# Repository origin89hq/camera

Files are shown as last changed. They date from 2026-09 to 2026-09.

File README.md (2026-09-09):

<picture>
  <source media="(prefers-color-scheme: dark)" srcset="https://raw.githubusercontent.com/origin89hq/brand/main/logos/origin89-horizontal-white.svg">
  Origin89
</picture>

# Origin89 camera

 Circuit specified, first copper drawn, nothing fabricated.

A trail camera that sends its pictures to the cabin over a Wi-Fi HaLow mesh,
so a site four hours from a road can be looked at without driving out. One
board, populated three ways: the camera, a relay that extends the mesh, and
the base at the cabin that talks to the controller. The processor is the
ESP32-P4 with a MIPI camera, chosen for night pictures; the radio is a HaLow
module.

| File | What it is |
| --- | --- |
| [CAMERA-MESH.md](CAMERA-MESH.md) | The product: what it does, the mesh, the power budget, what has to be measured before anything is built |
| [board/CAMERA-NODE.md](board/CAMERA-NODE.md) | The circuit specification the schematic is drawn from: blocks, rails, pin budget, the decisions left to draw time |
| [board/CAMERA-LAYOUT.md](board/CAMERA-LAYOUT.md) | The placement and routing rules, numbered `C-nn`, with their reasons |
| [board/layout/](board/layout/) | The placement and routing scripts that produced the first copper, in the order they run |
| [drawings/](drawings/) | The build and schedule drawings |

Every part is a candidate until it has been picked with its datasheet open.
The next step is the night-picture test on the P4 evaluation board; the
schematic is drawn against the result, not before it.

## Design source and exports

Design source: [`board/easyeda/origin89-camera.eprj2`](board/easyeda/), the
EasyEDA Pro project of this board alone, split out of the controller's.
Export of 2026-09-09: [`board/build/2026-09-09/`](board/build/2026-09-09/),
Gerbers, [bill of materials](board/build/2026-09-09/bom.csv),
[pick-and-place](board/build/2026-09-09/pick-and-place.csv), schematic PDF,
STEP and one DXF of every layer. The STEP is in Git LFS, so install
`git-lfs` before cloning or it comes down as a pointer file; it carries every
part but C59, which has no model. Nothing has been fabricated from it.

The Gerbers are checked by `tools/validate_gerbers.py`, the same script the
hardware repository runs on the controller, against
[`board/gerber-rules.json`](board/gerber-rules.json): the C-02 keep-outs at
the four mounting holes and the C-11 antenna void, layer by layer. It runs
in CI on every push and it is red on the 2026-09-09 export: the ground pour
reaches every mounting hole on all four layers, 29 mm² of copper inside the
3.5 mm keep-out at each, where C-02 wants none and C-03 wants the hole on
no net. The fix is the controller's: a prohibited region at each hole on
every copper layer, then the pours rebuilt. It is tracked as
[issue #1](https://github.com/origin89hq/camera/issues/1), and the check
goes green when the next export passes. Nothing has been fabricated from
this export, so no board carries the fault.

```sh
pip install gerbonara shapely
python tools/validate_gerbers.py board/gerber-rules.json board/build/2026-09-09/gerber.zip
```

Exports are filed with `tools/import_easyeda_export.py board <export folder>`,
the same way the [hardware repository](https://github.com/origin89hq/hardware)
files the controller's: the date becomes the directory and each file gets
the name its kind always gets.

## Licence

Design files and drawings under the CERN Open Hardware Licence version 2,
weakly reciprocal ([LICENSE](LICENSE)); the scripts under MIT OR Apache-2.0
([LICENSE-MIT](LICENSE-MIT), [LICENSE-APACHE](LICENSE-APACHE)).

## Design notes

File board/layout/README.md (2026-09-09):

# Camera node layout files

The DSL and placement files the camera board (`Camera_HaLow`, PCB3 in the
EasyEDA project) is laid out from, in the order they are used. The rules
they implement, and why, are in [CAMERA-LAYOUT.md](../CAMERA-LAYOUT.md).

| File | Tool | What it does |
|---|---|---|
| `camera-place.js` | `make_pcb_layout` | The whole-board placement: blocks, edge bands, satellites. Stochastic; six runs were needed and later ones regressed. Assemble the best, then repair by hand below |
| `padgeom.py` | library | Every pad's absolute position and shape, every part's centre and rotation, read from the newest router run under `$TMPDIR/easyeda-copilot-mcp/copilot-router/` (the PCB export has no pads). Any `run_pcb_router_dsl` call writes one, `camera-drc.js` being the cheapest |
| `p4_cluster.py` → `p4_cluster.json`, `p4-local.js` | `make_pcb_layout` on `p4-local.js` through the shim's `@local-placement` route, then `assemble_pcb_layout_on_current_pcbdoc` | The 48 parts pinned to the P4 (decoupling rings on all four sides, both crystals and their loads, the CSI series resistors, the flash, the core buck) at exact coordinates. Turns each two-pad part so its signal pad faces the chip, refuses to write while anything overlaps, prints each capacitor's pad-to-pin distance. Regenerating from the assembled board gives the identical file |
| `periphery.py` → `periphery.json`, `periphery-local.js` | same route as above | The repairs the checker found in the solver's placement outside the P4 cluster: the buttons off the U.FL, the LED boost inductor off its driver, the HaLow series resistors in the column at the module's pads with two straps moved out. Both generators share `Placement` in `padgeom.py` |
| `validate_camera_placement.py` | after every assembly | Measures every C-nn rule a placement can break, from the real pads, and refuses two parts that overlap. Run it on a fresh artifact (`camera-drc.js` first). Watched go red on the solver's placement before it was trusted |
| `csi_tracks.py` → `csi_tracks.json`, `csi-tracks-local.js` | same route as above, after the parts are placed | The seventeen nets the router could not do, drawn from the real pads: the MIPI lanes on both sides of their resistors (two crossings the connector's pin order forces, six vias), the D-PHY reference, both crystals with their loads. Refuses if any pad it relies on has moved, and if any pair's skew over the whole path passes C-20's 3.4 mm. C-20 says why |
| `p4_escape.py` → `p4_escape.json`, `p4-escape-local.js` | same route as above, after the tracks | The P4's escape: a 0.3/0.15 mm via under every signal pin in two staggered rows, a 0.127 mm stub from the pad, a stub from every supply pin to its ring capacitor, each checked against every other pad and the copper already on the board, the reason printed for anything refused. The router's own fanout left 26 pins without a stub; section 7 of the layout document says the rest, including what sixty-six partial nets do to the router's recovery stage |
| `dsn_plane.py` | after EasyEDA Pro's Autorouter DSN export, before freerouting | Makes the export routable by freerouting: the wires' layers renamed from EasyEDA's ids (1, 2, 15, 16) to the names the file declares (without it every hand track loads as "no shape"), Inner1 made a `power` layer with a GND `plane` on it (without it ground is 846 open connections routed as tracks), the escape's vias on the 0.3 mm padstack, and each rail's class width taken from `power_widths.py`: the export writes one class per net and gives all 153 the board default, which is how three 2 A rails came back routed at 0.2 mm |
| `power_widths.py` | on a fresh artifact, after any routing | Each rail of section 5 against the width its row demands, or the IPC-2221 width for its current. Compares the *widest* copper, not the narrowest: a rail thins legitimately at its last hop into one pin, so a minimum flags every escape spur, while a maximum below the rule means no part of it was ever drawn for its current |
| `ses_clean.py` | on freerouting's exported session, before EasyEDA imports it | Drops everything EasyEDA's import would get wrong: the `protect` copies of the hand copper (re-created at the default width on top of the originals), freerouting's own wires on the seventeen hand-routed nets (0.2 mm patches where the export had dropped a segment inside a pad), and any via on a hand-drawn via. It moves the remaining vias out of the session into a `-vias.json` for the shim, each at the size freerouting chose, because the import makes every via 0.6 mm, with the session's quotes stripped from the net names, because a via placed as `"3V3"` sits on a net of its own. Tracks go in through EasyEDA's import, vias through the shim; the import's Inner2 lands on EasyEDA's Inner8 and is moved by hand (Layer Manager to 8 copper layers, Find → Track on Inner8, Property → Inner2, back to 4) |
| `verify_hand_copper.py` | after every routing run or import | Every segment of the two hand files still covered on the board, on its own net and layer, allowing the assembler's splits. Routers rip hand copper as a blocker and importers rewrite it; this is the first number to read |
| `net_islands.py <net>…` | on a fresh artifact | The pieces a net is in, walked by geometry, with the pads and the free ends of each. The DRC names one pad per piece and `inspect_net` one length per piece; neither says which pads sit together, and a 49-pad `3V3` in three pieces was three guesses without this |
| `hand_route.py` | library, and `hand_route.py <net> x0 y0 x1 y1` | Draws one link on Top, Inner2 or Bottom through an A* grid with every other net's pad, track and via inflated by its width and the clearance, a via wherever one clears every layer and the hole-to-hole rule, then measures the result against the exact shapes (`verify`, `check`, `check_via` all return the gap; the rule is `CLEARANCE`). Use it for what freerouting leaves open, sequentially, each result added to the obstacles before the next. It moves nothing: when an escape via's pocket is walled, clear the walls' nets and redraw them after it (`ring_ground.py` is the worked example) |
| `ring_ground.py` → `finish/ripup.json` | `make_pcb_layout` on a `@local-placement` file, after `clearRouting` of the six nets | The rip-up that gave the P4's ring capacitors their ground: six freerouting nets out of the channel, a 0.3/0.15 via under each column capacitor, the top row stubbed to C33's via, the six nets back around it. Computed against the board as it stood before; the JSON is the record |
| `finish/*.json` | `make_pcb_layout` + assemble, in the order the layout document tells | What was drawn by hand after freerouting, as placed: the 3V3 links, the four clean redraws, the 3V3 and ADC_LIGHT rebuilds, I2C_SCL and HALOW_RST, the ground vias and stubs, and the rip-up. The freerouting result is not reproducible; these are |
| `camera-route-full.js`, `camera-route-3-copper.js` | `run_pcb_router_dsl`, in order, after `camera-clear-router.js` and the three hand files | Routing in two transactions: every net at once, with the router's whole budget (the RF run 50 Ω critical, the USB as ordinary nets, the buck's feedback first, the hand-routed nets restated, power by current), then the planes and the stitching (0.6/0.3 vias, island removal on every plane: a pour island that touches no via is a pad the DRC reports connected and is not). The three-pass plan died with the P4's escape: any pass with a shorter list ended in the router's recovery stage completing the escape's partial nets with detours; section 7 of the layout document says the rest |
| `camera-clear-router.js`, `camera-clear-net.js` | `run_pcb_router_dsl` | Remove the router's copper while keeping the hand-routed nets; remove one net's copper so a hand file can redraw it |
| `camera-drc.js` | `run_pcb_router_dsl` | Rules only. Run first when the board's global minimum differs from what the routing file asks, or the routing file is refused with `DSL_RULE_CONFLICT` |
| `camera-clear.js` | `run_pcb_router_dsl` | Removes every track, via and zone the router made. Checkpoint restore does not take on a PCB document; this does |

Placement DSL traps, learned on this board: y is downward in `edgePlace`
and offsets; a block holds at most 12 parts and must share a non-GND net;
`fixed()` and `componentGrid` only with role `connector`; passives of an
edge-placed part must be satellites anchored to its pins or they scatter.

`tools/copilot-shim`, named in several rows above, is a local proxy in front
of the EasyEDA copilot MCP server that serves a `@local-placement` file as if
the model had produced it. It is not published here. Without it the same
JSON has to be pasted into the editor by hand, which is what the generators
write it for.

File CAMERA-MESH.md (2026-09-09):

# Camera mesh: a sibling product

**Status: concept. Nothing here is measured yet.** This document exists so the
idea survives the conversation it was born in, in the house style: what fails
today, what the design prevents, and what has to be true before a board is
drawn. The gates on the board are measurements, not the calendar; they are
listed under "What must be true before a board is drawn". The controller's
first winter gates the *integration claims* and a combined sale, not this
board: the two products share a protocol and nothing else, which is what
lets them be built in parallel.

Working name: **the camera mesh**. A product name comes later.

---

## The one sentence

Trail cameras that talk to your cabin instead of a cell tower: no
subscription needed to work, working exactly where LTE does not, asleep all
winter, and the photos on your phone.

## What fails today

| What people buy | How it fails at km 43 |
|---|---|
| LTE trail cameras | Need a tower. The cabin has none. Monthly plan for a camera that cannot connect |
| Wi-Fi trail cameras | 2.4 GHz: 50–100 m through trees. You are standing next to it |
| SD-card cameras | Somebody drives out to read the card. The whole point of this company is that nobody drives out |

The gap is a radio that reaches the cabin and a schedule that lets everything
sleep, not a better camera.

---

## Three parts, one rule

How the mesh is built: a far camera behind a ridge reaches the cabin through a solar relay, a near camera reaches the mast directly, the base stores photos and hands them to the phone, and the controller only reads

*The camera behind the ridge goes through a solar relay; the one in sight of
the mast talks directly; the base keeps everything and hands it to the phone;
the controller only reads.*

**The rule:** the base needs nothing but 12 V and a place to stand. The
controller is an *option* it can plug into, never a dependency. A hunter with
no solar system installs the base, the cameras, and is done.

### Camera node

ESP32-P4 (MIPI camera interface, a hardware image processor, JPEG in
hardware, 12 µA asleep), a HaLow module, a PIR, a battery, an optional
palm-sized solar panel, IR illumination, an IP67 body with a glass window.
Sleeps at microamps. Wakes on the PIR, shoots, queues the JPEG on flash, and
goes back to sleep until its **wake window**, the only time its radio is on.

### Relay node

The same board with the camera unpopulated. Solar-powered because it holds
two windows instead of one (up and down). Store-and-forward: it receives in
one window, sends in the next. A relay is the exception, not the design (see
the topology section).

### Base

Sits in the cabin, powered by the bank (or a 12 V adapter where there is no
bank). HaLow access point on a high antenna, the master clock that hands
every node its schedule, and the same app protocol the controller already
speaks. A microcontroller, not a Linux box: the same class of part as
every other node, a microSD ring buffer instead of a disk, and a bridge to
the cloud over whatever internet the cabin has. The archive and the app live
on Cloudflare (R2, Workers, D1, Pages, the site's own stack); with no
backhaul, the phone reads the base's buffer over the base's own Wi-Fi.

A Linux single-board computer was the first draft, and it was a reflex, not
a decision. What it bought (a disk and a local app) the cloud buys for
nothing, and what it cost was real: 3–5 W continuous (~100 Wh a day) off the
bank the controller is guarding in January, a filesystem on an SD card that
the first power loss corrupts, and ~$150 instead of ~$40.

---

## Standalone by design, integrated by option

This is the question that decides the architecture.

| | Standalone | With a controller present |
|---|---|---|
| Power | 12 V in, its own fuse | The same bank. The base is a load the controller can shed under low state of charge, through a relay output it already has |
| Storage | MicroSD buffer at the base, the archive in R2 | The same. The controller never touches photos |
| App | The base is a device in the app | Same app, one more device on the site |
| Readings | Shown by the base | Node batteries, link health, photo counts flow to the controller as readings, like a charger's. They appear beside the bank's |
| Notifications | Through the base's own backhaul | Through the controller's existing cloud path; one pairing, one place |
| Failure of the other box | Not noticed | Not noticed. Coupling is data, never control |

Mechanically: the base is one entry in the controller's device catalogue
and one driver, the same `add-device` path every meter and charger took.
The controller does not learn anything about cameras; it learns that a device
reports battery percentages and a counter. That is the whole integration, and
it is why the two products cannot take each other down.

---

## Radio

**802.11ah (Wi-Fi HaLow).** 902–928 MHz, licence-exempt in Canada
(RSS-247) and the US (FCC 15.247). 1 or 2 MHz channels. Hundreds of kbps to a
few Mbps, which is a photo in seconds and a short clip in a minute.

Silicon: Morse Micro MM6108 (SPI/SDIO modules, Linux and RTOS SDKs) or
Newracom NRC7394. **Certified modules only**: no discrete RF on a product
that has to pass RSS-247 with a hunting-season deadline behind it. The choice
between the two is made after the range test, not before.

### Topology: star first, mesh where the terrain says so

The base's antenna goes up: a mast or a tree, 6–8 m. From there, 900 MHz
covers a 1–2 km radius over mixed forest and cutovers. Most cameras talk to
the base directly. Relays exist only for nodes behind a ridge or beyond the
radius, and the core of any layout is a loop, so one dead relay does not
orphan the far side.

On the property that prompted this document the sketch is nine nodes around
a base, hops of 500–750 m, a core loop, one 1 km link and one three-hop
tail. Three lessons from drawing it:

- **Elevation profile before distance.** At 900 MHz over 700 m the first
  Fresnel zone wants ~7–8 m of clearance at mid-path. A hill between two
  nodes kills a link that distance alone would allow. Check every link's
  profile in Google Earth before buying a single module.
- **A long link wants a Yagi, not a relay.** A 900 MHz Yagi is 40 cm and
  +10 dBi. It turns a marginal 1 km link into a solid one and costs less
  than a solar relay.
- **A tail of three relays is three single points of failure.** Acceptable
  for latency (see the schedule), questionable for reliability. Prefer a
  directional link that skips a hop.

### The schedule is the power budget

A mesh where relays stay awake needs mains. This one does not, because a
trail camera does not care about latency: a photo that arrives in five
minutes is a photo that arrived.

- The base holds the master clock and assigns every node a wake window
  through 802.11ah's Target Wake Time. Everything else sleeps.
- A node wakes for ~200 ms every ~10 s, exchanges what is queued, sleeps.
  A relay opens its downstream and upstream windows back to back.
- Latency = hops × period. Three hops at 10 s is half a minute.
- Clocks drift: a ±20 ppm crystal is 1.7 s/day. Guard time around each
  window, resync on every contact. A node that misses N windows falls back
  to a wide listen until it hears the base again. This is the fail-safe,
  and a test must fail loudly if it is ever removed.

Thirty seconds of the schedule: the camera wakes 200 ms every 10 s, a photo taken at 2 s reaches the relay at the 10 s window and the base at the 20 s window; only the base stays awake

*Thirty seconds of the schedule: nobody listens outside its window, the
photo advances one hop per window, and only the base pays for staying awake.*

At 2 % listen duty a HaLow module averages ~1 mA. The arithmetic below rests
on that number, which is a datasheet number until a multimeter says
otherwise, at room temperature and in a freezer.

---

## Power

| Node | Source | Budget | Why it holds |
|---|---|---|---|
| Camera, battery only | 4× AA lithium primary (L91) or LiFePO₄ 18650 | ~1 mA average + photo bursts → a season | Lithium primary works at −40 °C; LiFePO₄ does not charge below 0 °C, which is fine for a cell that is not being charged |
| Camera, solar | LiFePO₄ + 2 W panel | Indefinite in summer, a season in winter | Same charge-below-freezing rule the controller enforces on the bank. Reuse the frost logic, do not rewrite it |
| Relay | LiFePO₄ 6 Ah + 5 W panel | Survives January at ≤5 % duty | To be checked against the controller's own season simulator, which already models insolation at this latitude |
| Base | The cabin bank, or a 12 V adapter | ~0.3–0.5 W awake | It is the one node allowed to stay awake. Being a microcontroller with a HaLow module, staying awake costs a tenth of what a Linux board would take from the bank |

---

## Data

### Thumbnails first, because the radio is the battery

Sending a 300 KB photo over HaLow is ~5 s of transmit at ~300 mA, about
0.4 mAh. A windy day that trips the PIR two hundred times for waving
branches burns 80 mAh on nothing, against ~24 mAh for everything else the
camera does that day. False triggers are what empties a battery in
January, not an app annoyance. So the filter lives before the radio, and
the cloud does the rest:

- The camera always sends a **thumbnail** (~10 KB, thirty times cheaper).
  Full resolution stays on its card and travels only when asked for, by
  the cloud after classification or by a thumb in the app, through the
  next wake window. One extra window of latency for the full picture, and
  a thirty-fold cut in radio energy on everything that turns out empty.
- A small classifier on the ESP32-P4 (animal / person / vehicle / empty,
  a few hundred milliseconds on its two cores) gates what gets queued at
  all. It is tuned to never be silently wrong: unsure means send the
  thumbnail and let the cloud decide. A false negative is a lost moose; a
  false positive is 10 KB.
- In the cloud, Workers AI tags every thumbnail (species, person, vehicle,
  empty), and the app is built on those tags: "show me the bear", not
  "scroll 400 pictures of a spruce in the wind".

### Volumes

- The first sensor is a native 5 MP (2592×1944) on a MIPI module,
  the class the good trail cameras carry; the "33 MP" and
  "36 MP" on the boxes are interpolated in firmware. A full 5 MP JPEG is
  ~1 MB; the delivered "standard" picture is a 1600×1200 at 150–300 KB;
  the thumbnail is ~10 KB. A busy camera makes 50 triggers a day: 500 KB
  of thumbnails, a few standard pictures on request, the full frames on
  the card.
- What decides a trail picture is **trigger speed** (the market says
  0.2–0.5 s; a microcontroller waking and initialising the sensor is
  nearer 0.6–1 s unless the sensor idles in standby, which costs current;
  measured before the board, see below), **night** (the IR array, the
  pixel size and the image processor's noise handling, not resolution)
  and the **lens**, not megapixels. Night is why the node is an ESP32-P4 and
  not an ESP32-S3: the S3 has no MIPI receiver and no image processor, so
  a parallel-bus OV5640 delivers the ESP32-CAM class of picture; the P4
  puts a real ISP behind the same class of sensor, on the same sleep
  budget, and the camera module plugs into the Raspberry Pi connector so
  the sensor can change without the board changing. The reasoning and
  the costs are in [CAMERA-NODE.md](board/CAMERA-NODE.md).
- **Photo only, by decision.** A 10 s 720p clip is ~2 MB: thirty seconds
  of HaLow transmit and ten times a photo's energy to capture and encode,
  which is what the scheduled mesh and the battery table are built to
  avoid. Video is also what forces a dedicated camera SoC, a
  microphone and a clip pipeline into a trail camera. The first board
  shoots stills; a **burst** (three frames in a second, three times a
  photo's cost, no new silicon) answers the question video is usually
  bought for: what did it do. Video is a later revision's question,
  gated by demand, not by technique.
- **Three copies, by design, because the cabin's internet is optional.**
  The camera keeps its own on microSD (every trail camera has, forever),
  and it is the copy nothing can lose. The base holds a microSD ring
  buffer (a few GB is months) and drains it to R2 whenever the backhaul is
  up. R2 is the archive and what the app reads: 10 GB free, no egress fee,
  and a busy site makes 15 MB a day.

### Free and paid, without lying about "no subscription"

The product works with nothing paid: the camera's own card, the base's
buffer, and the latest N pictures per camera kept in R2. Paying buys months
of retention, the species tags and the alerts. R2 itself costs cents (a
busy camera is 15 MB a month of thumbnails), so the subscription is for the
app, the classification and the work, not for disk, and the pitch says "no
subscription needed", never "no subscription".
Free tier expiry is a ring, oldest first, and the camera's card still has
everything.

- **The link is IP.** HaLow is Wi-Fi; the nodes speak the existing site
  protocol over TCP: framing, auth and pairing already exist and are
  specified against the failures that matter. Nothing new on the wire.
- Remote: the app reads R2: thumbnails first, full resolution on tap.
  Off-grid with no backhaul, the phone reads the base's buffer over the
  base's own Wi-Fi when it is at the cabin: same app, local mode.

---

## What goes wrong, and what catches it

| Failure | What the design does |
|---|---|
| A node's battery dies in January | The base shows last-seen and a battery trend for every node; the core loop routes around a dead relay |
| Clock drift closes a window | Guard time, resync on contact, wide-listen fallback after N misses |
| A relay spends its budget forwarding for others | Per-node energy accounting at the base; the app shows who is carrying whom |
| A moose relocates a camera | Missed-windows alert with last-known position |
| Wind trips the PIR three hundred times a day | The on-camera classifier drops the obvious empties before the radio; the rest go as 10 KB thumbnails; the cloud tags them; the full pictures never leave the card unless asked |
| The classifier is wrong | It is biased to send: unsure means thumbnail. The card keeps every full frame, so a miss in the cloud's view is recoverable on the next visit or on request |
| Another 915 MHz radio on the property (LoRa, Meshtastic) | Channel scan at install; HaLow's channel plan leaves room |
| The cabin has no internet, or Starlink is off for the winter | Nothing is lost: the camera's own card has it, the base's buffer has months, and the app reads the base locally. R2 catches up when the link returns |
| Base buffer fills before the link returns | Ring buffer, oldest first; the camera's card still has everything |
| A firmware update bricks a node 700 m into the woods | A/B slots on every node, updates ride the same windows slowly, and **no over-the-air update until a bootloader exists and an image has been verified on a bench**; the controller's rule, unchanged |
| The controller is removed | Nothing. The base never depended on it |

---

## What an LTE trail camera looks like inside

A teardown of one of the mass-market LTE cameras, its main board already on
a fourth revision, which is its own lesson, confirms the shape and corrected
two lines of the table below:

- The image sensor sits on the main board behind a screwed lens holder,
  with a **mechanical IR-cut filter** beside it. Without the filter a
  camera is pink by day or blind by night. It was missing from the first
  draft of this document.
- The PIR is a large pyroelectric can behind a Fresnel lens in the
  housing, 25–30 m of detection. A hobby PIR module sees three metres.
- The IR flash driver is a separate front board in the cover: boost
  converter, 0.68 Ω sense shunt, a MOSFET per LED string, fed over an FFC.
  High current lives next to the LEDs, not across a cable. One board is
  possible if the enclosure puts LEDs and board on the same face.
- The SoC is a dedicated camera part with an ISP and H.264, which is why
  its video is decent, and a large part of why the camera costs and
  draws what it does. Stills do not need it; this product ships stills.
- An LTE module under a shield, a coax to a wire antenna, a microphone,
  a debug header, eight test points. The radio and the microphone go
  away with the video; the test points are a habit worth stealing.

## Rough bill of materials

| | Parts | Order of cost |
|---|---|---|
| Camera node | ESP32-P4 with its flash and core buck (photo only by decision, though the encoder for video is on the chip), a MIPI camera module on the Raspberry Pi 15-pin connector (OV5647 NoIR first) behind a screwed lens holder, **mechanical IR-cut filter** with its H-bridge (colour by day, IR by night), HaLow module (~$20), a **real pyroelectric PIR** (Excelitas/Murata class) behind a Fresnel lens tuned to the field of view (not a hobby module), LiFePO₄ or 4×AA, small MPPT charger (CN3791/BQ25185), 8–12 850 nm IR LEDs on a **boost driver with a current-sense shunt**, IP67 body with glass | $60–80 |
| Relay node | Same PCB, camera unpopulated, 5 W panel, 6 Ah LiFePO₄ | ~$40 + panel and cell |
| Base | The same board with the HaLow module in access-point mode, microSD, and an ESP32-C6 module fitted for the Wi-Fi uplink to the cabin's internet (the P4 has no radio of its own), a box in the family's shape and faceplate grammar | ~$45 |

---

## What must be true before a board is drawn

Conditions, in order. Each one is a measurement, not a meeting.

1. **The range test on the actual property.** Two development modules, the
   base position and the first two hops of the sketch. Pass: usable
   throughput at both points with more than 10 dB of margin, through the
   trees that are actually there.
2. **Sleep current of the chosen module**, measured, at room temperature and
   in a freezer. The whole power table above is a datasheet claim until then.
3. **Access-point mode, TWT scheduling and relay chaining work on a
   microcontroller host, without Linux.** This is the choice between the
   two chip vendors: the Newracom NRC7394 is a standalone SoC that runs an
   access point in its own SDK; the Morse Micro MM6108 has an MCU SDK, but
   its access point has classically lived in hostapd on Linux. If neither
   does it, the fallback is application-level store-and-forward with the
   module alternating between station and access point; decide which
   before designing the relay's power budget or the base.
4. **One photo, two hops, end to end**, with latency and millijoules per
   photo measured. That number sizes every battery in the table.
5. **Trigger speed from deep sleep**, PIR edge to first frame captured,
   with the sensor cold and with it idling in standby, and the standby
   current that buys. Under half a second is the market; the trade is
   decided on the numbers.

Then: a base on a development kit, two development nodes in the field, and
a board.

None of this waits on the controller. The product is independent of it, and
the five measurements fit inside the weeks the controller's boards spend at
the fab.

What the controller's first winter *does* gate is narrower: the integration
claims (shedding the base under low state of charge, notifications through
the controller's cloud path) and any combined sale. The camera mesh borrows
the controller's protocol, frost logic and season simulator (all of which
run and are tested on a host today) and a camera node in the field is a
second proving ground for them, not a consumer waiting on the first.

---

## Relationship to the family

Same identity: the wordmark, the km 43 badge, the faceplate grammar, the
app. Same wall, same bank, same box shape. A different job: the controller
keeps a site alive; this one tells you what walked past. They share a
protocol and nothing else, which is what lets each be sold without the other.

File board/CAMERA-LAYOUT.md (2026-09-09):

# Camera node — PCB layout requirements

What the camera node's board must satisfy, and **why**, in the form
[LAYOUT-REQUIREMENTS.md](https://github.com/origin89hq/hardware/blob/main/boards/controller-a/LAYOUT-REQUIREMENTS.md) gave the controller. The
circuit's reasoning is in [CAMERA-NODE.md](CAMERA-NODE.md); this file
extracts only what constrains placement and routing. Requirements are
numbered `C-nn`.

Unlike board A, this board is not going to a layout house: it is placed
and routed here, from this file, with the same discipline. Every
distance that matters is written down before the copper exists, because
nothing in a netlist records which distances were deliberate.

---

## 1. What the board is

One PCB, populated three ways (camera, relay, base). It sits **behind
the front window of a trail-camera housing**, component side toward the
scene, battery behind it. That decides the whole geometry:

- the **top side faces the window**: the camera flex, the pyro, the
  light sensor and the IR LEDs all look forward, so they are top-side
  parts, and there is no bottom-side assembly at all (one pass at JLC,
  like board A);
- the **bottom edge is the service door**: the OFF/SETUP/ON switch, the
  USB-C and the microSD sit on it, behind one gasket, and nothing else
  does;
- the **antenna leaves at the top**: the U.FL is near the top-left
  corner, the pigtail goes straight up to the RP-SMA bulkhead on the
  housing's roof;
- the housing is **bought, not drawn**: the makers of the generic trail
  cameras sell the empty shell (front and back, gasket, IR window, lens
  opening, Fresnel, battery bay, latches, tripod nut) and a plain one
  takes paint. Nobody publishes the PCB size of those shells, but every
  body in the class is **90 mm wide** (Suntek HC-801 135 × 90 × 76,
  Stealth Cam DS4K 150 × 90 × 83, and the rest of the class the same), so a board
  cannot be wider than about 80 mm, and a clamshell keeps its batteries
  in the back half, so the front half offers more than 100 mm of height.
  **The board is designed at 80 × 100 now, on that reasoning, and
  adjusted to a measured shell before the boards are ordered**. A
  shell arrives in the time routing takes, and if its cavity, lens hole,
  PIR window, IR window, battery contacts, antenna boss or door disagree,
  C-01, C-02 and C-06 to C-09 are redrawn and the periphery re-routed.
  What survives a change of outline is everything pinned to the P4
  (section 4), which is why that is placed first and by hand. The front
  board for a bigger LED array is whatever the shell's lid holds.

## 2. Mechanical and stackup

| ID | Requirement | Why |
|---|---|---|
| **C-01** | Outline **80 × 100 mm, portrait**, 1.6 mm FR-4, origin at the board centre (x ±40, y ±50); the design dimension, **checked against a measured shell before the boards are ordered** (section 1) | The compact estimate for 214 footprints at density 0.4 is 99 × 66 mm; a portrait 80 × 100 gives the same area with the shape a camera housing wants (tall, narrow, lens above pyro above door), is the widest board a 90 mm body admits, and stays inside JLC's ≤100 × 100 price tier. Four layers with a 0.35 mm QFN and three differential pairs want the routing room, not a denser board. Routing goes ahead on this outline; what a shell can still move is the periphery, and the periphery is a day to re-route |
| **C-02** | Four **M3** holes, 3.2 mm finished drill, **3.5 mm keep-out radius on all copper layers and both silkscreens**, centres 4 mm in from each corner (**±36, ±46**) | Nylon standoffs in a plastic housing, as on board A. The keep-out is a hair larger than A-02's because this board has inner planes: a plane flashed at a hole is a short to a screw head |
| **C-03** | Holes on **no net** | Plastic housing, nothing to bond to; the cell's negative is bonded once, elsewhere, if at all (A-03) |
| **C-04** | **4 layers: L1 signal, L2 solid ground, L3 power, L4 signal**, JLC04161H-7628, ENIG | L2 is the reference under the MIPI pairs, the RF trace and both crystals. It is unbroken beneath all of them, without exception (A-05's rule, same reason) |
| **C-05** | **All parts top side.** No bottom assembly | One JLC pass, one pick-and-place file, one side to inspect; the bottom faces the battery and carries only copper |
| **C-06** | **Service door band: the bottom 12 mm of the board** (y from −50 to −38) holds `J6` (microSD, card exits the bottom edge), `J1` (USB-C, overhanging), `SW3` (slide switch, actuator through the door), left to right at about x = −20, 0, +22, and **nothing else but their own satellites** (the USB's CC resistors and ESD diode, the card's pull-ups and TVS, which C-37 puts at the connector) | Three things a person touches, one gasket. The widths are 17.2 + 10.4 + 14.3 = 42 mm of a 64 mm edge between the corner keep-outs, so they fit with finger room. A fourth part on that edge means a wider door and a bigger housing |
| **C-07** | **LED band: the top 10 mm** (y from +40 to +50) holds `D12`–`D21` in one row at 6 mm pitch and nothing else | Ten 3528 emitters in a line behind one strip of window. The flash driver sits just below the band; the string's return runs straight back to it |
| **C-08** | **The optical axis is the board's vertical centreline.** `J4` (camera flex) is pinned at **x = 0, 8 mm above the board centre**, and the P4 follows it: within **15 mm pad-to-pad of the P4's CSI pins** (`U1` pins 42–48) through the six series resistors `R24`–`R29`, the resistors at the P4 | The lens sits on the housing front directly over the connector, the way every trail camera on the market is laid out: IR panel above, lens centre-high, PIR window below on the same axis. The D-PHY lanes are the fastest thing on the board (up to 1.5 Gbps per lane), so the P4 goes beside the lens, not the other way round. The number was 12 and the first placement measured 12.6–13.1: the difference is the connector's pinned height, which the shell will set, and 3 mm of D-PHY trace is 20 ps against a 667 ps unit interval. Skew and coupling (C-20) are the constraint at these lengths, not loss |
| **C-09** | `U13` (pyro) on the same axis, **about 28 mm below the board centre** (36 mm under the lens, above the door band), its lens window free of tall parts within 8 mm; `Q3` (light sensor) beside it | The Fresnel lens in the housing is aimed at the pyro; the light sensor must see the same sky. Tall parts (the C6 module, the HaLow module, the inductors) cast shadows on both. `L2`, the core buck's 1.5 mm inductor, is exempt: it is off whenever the pyro is the only thing awake (the P4 drives `EN_DCDC` low in deep sleep) and it sits at the P4's FB/EN corner, which is where C-32 needs it |
| **C-10** | `J8` (U.FL) on the **left edge, upper half** (y ≈ +25), `U14` (HaLow module) beside it with its `ANT_WIFI` pad facing `J8`, the RF run `U14.40 → R76 → J8.1` **under 15 mm, 50 Ω coplanar on L1 over solid L2**, ground stitched both sides | An RF pigtail inside a plastic box is the only path the radio has; the on-board run is loss and mismatch that no antenna gain buys back. The two unpopulated shunt pads of the π-network sit on this run |
| **C-11** | `U11` (ESP32-C6 module, base only) at the **right edge, upper half**, antenna end at the board edge, **no copper on any layer under its antenna keep-out**, and Espressif's ≥ 15 mm to any housing material | A module antenna over copper is a module that does not connect (A-15, same words, same reason). It is only fitted on the base, but the void is in every board |
| **C-12** | `J2` (cell) and `J3` (solar) on the **left edge, lower half**, `JP1` (sleep-current jumper) beside `J2` | The battery is behind the board; its lead comes round the left edge. The jumper is the one thing the bench touches on every board (the sleep measurement), so it stays at the edge with the cell |
| **C-13** | `SW1`/`SW2` (boot/reset) inside the board, not on the door edge; the 18 test points in one accessible grid at the **right edge, lower half** | These are bench controls: USB Serial/JTAG flashes the P4 without the boot button (CAMERA-NODE.md). Nothing a person needs in the field is anywhere but the door |

## 3. Impedance

| ID | Net | Target |
|---|---|---|
| **C-20** | `CSI_CLKP/N`, `CSI_DATAP0/N0`, `CSI_DATAP1/N1`, and their `CSI_A_*` continuations past `R24`–`R29` | **100 Ω** differential ±10 %, MIPI D-PHY: 0.127 mm lines at a 0.25 mm gap in the L1 ground flood over unbroken L2 (grounded coplanar, 103 Ω by the router's solver; the fab's report is the witness). **Routed by hand** (`tools/camera-layout/csi_tracks.py`), because the P4 orders its lanes D1, CLK, D0 with the clock's N before its P, and the Pi connector wants CLK, D1, D0 with P before N: the clock must cross itself and D1 must cross the clock, and no placement removes either. Two layer changes, kept apart so two layers suffice: `CSI_CLKN` dips to L4 between the P4 and `R28` (two vias, the clock's P never interrupted), and the `CSI_A_DATAP1/N1` pair runs on L4 from its resistors to two vias in the 1.6 mm between the connector's rows (four vias). **Six vias in all, none on the clock's P, none on D0**; a return via beside each (pass 3). Intra-pair skew is **3.4 mm by construction** (the connector's contacts sit in two rows 3.4 mm apart), which is 23 ps against a 100 ps budget; the ±0.15 mm this row once asked for was impossible on any board with this connector. The series resistor is part of the path, not the end of it. **The number is the whole lane's**, chip pad to connector contact across both halves, and `csi_tracks.py` measures it (3.26, 2.6 and 1.1 mm). EasyEDA's pair rule sees one half at a time: the connector half carries the 3.4 plus 0.3 of routing, the chip half 0.4–1.2 the other way, so its `differentialPair` length tolerance is set to **3.8 mm** (the bound of a half, not of the lane), and the DSL cannot write it (`camera-drc.js` says why) |
| **C-21** | `ANT_MOD` / `HALOW_ANT` | **50 Ω** single-ended coplanar on L1, L2 reference, ≤ 15 mm |
| **C-22** | `USB_DP/DN`, `USB_DP_C/DN_C`, `USB_DP_J/DN_J` | Two ordinary nets routed together on L1, **not a declared pair**. Declared as 90 Ω pairs they failed the router's impedance stage twice (the path crosses `R18`/`R19` and starts at a 0.35 mm corner), and each failure dropped the router into recovery routing over the whole board (section 7). Full-speed USB on a service port tolerates the loss |

## 4. Placement

| ID | Requirement | Why |
|---|---|---|
| **C-30** | `U1` (P4) near the board centre, rotated so its CSI edge (pins 34–52) faces `J4` | The QFN's bottom edge carries flash, DSI, CSI and USB; the flash goes left of it, the camera below it, the USB down to the door |
| **C-31** | `Y2` (40 MHz) under the capacitor ring with its near pad within **5 mm** of `U1` pin 100 and its far pad within **6.5 mm** of pin 99 (a four-pad crystal's pads are diagonal: sat in the ring, both were under 3 mm, and the eight pins behind its body had no way out; the escape of the whole side is worth 1.3 mm of crystal stub), `C37`/`C38` beside it; `Y1` (32 kHz) within **5 mm** of pins 104/1 with `C39`/`C40`; both crystals **≥ 10 mm from `L1`, `L3`, `L4` and their switch nodes**, and **≥ 5 mm from `L2`** (the core buck is 0.5 A at 1.1 V from 3.3 V, over an unbroken L2, and the P4 wants it at its own pins; the first placement could not hold 10 mm to it without pushing the crystals off theirs); no track under either crystal on any layer, unbroken L2 beneath | A-17 and A-28, same aggressors, same victims. The 32 kHz crystal is also the wake schedule: its ±20 ppm is the whole reason the mesh's windows line up. **Pin the P4 to the centre and the crystals to the P4.** Clearance rules alone lost three times on board A |
| **C-32** | Core buck `U7`/`L2`/`C27`/`C36`: input capacitor to `VIN`/`GND` loop minimal, `L2` at the `SW` pin, `C27` at the `VDD_HP` side, the `FB_DCDC`/`EN_DCDC` lines short and away from `L2` | The P4 regulates this loop through its own `FB_DCDC` pin; a long feedback trace is an antenna into the core supply |
| **C-33** | Buck-boost `U6`/`L3`: `L3` between `L1`/`L2` pads, `C47` at `VIN`, `C48`/`C49` at `VOUT`, exposed pad on a via array to L2; `≥ 10 mm` from both crystals and from `U13` | The 2 A rail. Its exposed pad is the only heatsink it has |
| **C-34** | `3V3` buck `U3`/`L1`: `C7` at `VIN`, `C10` at `VOUT`, `L1` at `SW`; the whole cluster **≥ 10 mm centre-to-centre from `U13`** and ≥ 5 mm from `Q3` | The pyro reads microvolts. The always-on converter is the one aggressor that never stops. The light sensor is a phototransistor into 100 k, read at 1 Hz through 100 nF; an inductor's field does not reach it, so it may sit closer than the pyro. All distances in this document are centre-to-centre unless stated |
| **C-35** | Every P4 supply pin has its capacitor **within 3 mm** of the pin, on L1, returned to L2 by its own via: `C1`/`C2` (pin 9), `C3` (21), `C23`/`C24` (26), `C4` (62), `C28`/`C29` (59/67/72), `C30`–`C32` (41), `C33`/`C34` (30/71), `C35` (74), `C17` (75), `C25` (76), `C18`/`C19` (77), `C5` (85), `C26` (91), `C14` (96/101), `C15`/`C16` (102), `C20`–`C22` (51). Where a pin has two or three, the **first** is within 3 mm in the ring at the pins; the others sit in an outer column within 10 mm. **The pin capacitors are 0402** (100 nF C1525, 1 µF C52923, 10 nF C15195, 22 pF C1555, all JLC basic parts), in a ring 6.55 mm from the P4's centre at 1.15 mm pitch; the 10 µF and 4.7 µF bulk parts stay 0603 in the outer column | The EV board's decoupling is copied pin for pin; the only way to lose it is distance. A 0.35 mm QFN side is 10 mm and holds six 0603 parts; the left side has eight supply pins on six nets, and with 0603 parts pins 71 and 73 measured 7–11 mm from their nearest capacitor. 0402 puts one at every pin at 1.1–1.6 mm. The bulk parts do not move to 0402: a 10 µF 0402 is a 6.3 V part that loses half its capacitance at 3.3 V. The placement solver put every one of these 3–6 mm out and both crystals 9–15 mm out, six runs in a row, and two local repairs ended in overlaps. So **everything in this section is placed from a file, not by the solver**: `tools/camera-layout/p4_cluster.py` writes the 48 positions from the real pad geometry, refuses to write while anything overlaps, prints each capacitor's pad-to-pin distance, and the shim's `@local-placement` route moves exactly those parts and nothing else |
| **C-36** | `U1`'s exposed pad on a **5 × 5 via array** to L2 | 0.5 A core current and a 400 MHz chip; the pad is the thermal and the ground path |
| **C-37** | `D5`–`D10` (microSD TVS) at `J6`, on the connector side of the pull-ups; `D1` (USB ESD) at `J1`, before `R18`/`R19` | A-11: a clamp downstream of what it protects protects nothing |
| **C-38** | `R20` (`CSI_REXT` 4.02 k) within 3 mm of pin 48, its return to L2 at the pin | The D-PHY's reference current; a long trace on it is jitter |
| **C-39** | `U14`'s 22 Ω series resistors `R57`–`R59` at the module's SDIO pads; the 13 strap pull-downs may sit anywhere within 10 mm of the module | The straps are DC; the SPI lines run at up to 50 MHz |
| **C-40** | Flash `U8` within **10 mm** of `U1` pins 27–33, `R15` at `U8` pin 1 | QSPI at up to 80 MHz; the EV board keeps it this close |
| **C-41** | `U12`/`L4`/`D11`/`C62` (LED boost) directly below the LED band, `C62` at `D11`'s cathode, `R55` (shunt) with its ground return to L2 at `U12` pin 4 and `R56`/`C64` at the shunt, not at the P4 | The switch node swings 15 V at 1.2 MHz; the shunt is a 200 mV measurement |
| **C-42** | `U9` (IR-cut driver) and `J5` within 15 mm of `J4` | The filter's coil rides the same lens holder as the flex |

## 5. Power

| ID | Net | V | A | Note |
|---|---|---|---|---|
| **C-50** | `VCELL`, `VCELL_J`, `VSYS` | 3.0–4.5 | 2.0 | Cell to charger to both converters. ≥ 1.0 mm on L1/L3, the charger's `SYS` and `BAT` pins on short wide copper |
| **C-51** | `3V3` | 3.3 | 0.75 | Always-on rail: P4 domains, flash, pyro, C6. An L3 island |
| **C-52** | `3V3_HP` | 3.3 | 2.0 | Buck-boost to the three switches. ≥ 1.0 mm |
| **C-53** | `3V3_CAM`, `3V3_RF`, `3V3_SD` | 3.3 | 0.5 / 0.5 / 0.3 | Switched sub-rails. `3V3_RF` reaches `U14`'s `VBAT`/`VDDIO`/`VDD_FEM` on ≥ 0.5 mm |
| **C-54** | `VDD_HP` | 1.1 | 0.5 | The core. `L2` to the four `VDD_HP` pins on ≥ 0.8 mm copper, `C27` at the inductor, then the pin capacitors |
| **C-55** | `VLED` | ≤ 38 | 0.15 | The open-string clamp reaches 38 V: 0.3 mm clearance around `VLED` and `FLASH_SW`, `C62` is the 50 V part |
| **C-56** | `1V8_PSRAM`, `2V5_MIPI`, `VDD_FLASH` | – | ≤ 0.05 | The P4's own LDO outputs. Each capacitor at the output pin, then a short run to the load pin |

## 6. Silkscreen

`OFF · SETUP · ON` beside the switch with an arrow for each position;
`USB` and `microSD` beside their openings; `+` at the cell connector;
the board name and revision at the right edge. Reference designators
everywhere, 1 mm text, readable under a headlamp.

## 7. Acceptance

Zero DRC violations; every `C-2x` impedance reported by the fabricator;
the placement checker green (`layout/validate_camera_placement.py`,
which measures every rule above from the real pads, the router's input
artifact rather than the pad-less PCB export board A's checker had to
calibrate around, and refuses two parts that overlap); the antenna void and
the hole keep-outs checked on the Gerbers by `tools/validate_gerbers.py`
against `gerber-rules.json` beside this file, green, which the 2026-09-09
export is not: its pours reach every mounting hole (C-02, C-03, issue #1);
and one rendered picture of the board, top side, to compare against the
measured shell before the five boards are ordered.

The checker was made to go red before it was trusted: on the solver's
placement it fails C-31 five ways (both crystals off their pins, the
40 MHz one 9.3 mm from L3) and C-38, and it found three overlaps the
solver had left (`J8`/`SW1`, `L4`/`U12`, `C63`/`L4`) that nothing else
had noticed.

Two things the tools cannot check and a person must, learned on the first
routing attempt: the router's copper pours have no holes, so the C6
antenna void (C-11) is a prohibited region drawn in EasyEDA after routing
(**x 33.5 to 40, y 14 to 29, every copper layer, forbidding tracks,
copper, fill and plane zones but not components**, since the module's own
body sits in it), the pours rebuilt and the stitching vias under it
deleted; and the
router's line-width floor is 0.127 mm, so the MIPI pairs reach 100 Ω with
0.127 mm lines and a 0.25 mm gap, not with thinner lines (the
fabricator's impedance report is the witness, not the DSL's calculator).

**The P4's escape is drawn, not routed** (`layout/p4_escape.py`).
The router's own fanout left 26 of the QFN-104's 0.35 mm pins without a
legal stub, and five passes over the ring never got past 118 of 151 nets.
So the escape is a file: a 0.3/0.15 mm via under every signal pin, in two
staggered rows 5.65 and 6.2 mm from the chip's centre (neighbouring vias
0.65 mm apart, a stub passing the next pin's via with 0.137 mm to spare),
a 0.127 mm stub from the pad, and a stub from every supply pin to its ring
capacitor (via, turn, pad centre). Every via and stub is checked against
every other part's pads and the copper already on the board before it is
written, and anything refused is printed with its reason rather than drawn
wrong. JLC's four-layer floor is a 0.15 mm hole in a 0.25 mm via, and the
board's via rule follows the escape at 0.3/0.15. The router then starts
from vias, never from the package.

The escape changes one thing about the router, learned by watching two
runs. Sixty-six nets now start as partial copper (a stub and a via), and
when the router's impedance stage fails on any declared pair it falls back
to *ordinary recovery*, which completes every partial net on the board,
in or out of the pass's list: 1100 mm of track on fifteen nets that were
never asked for, half of it dangling, twice. The USB pairs were what
failed (C-22 says why they are ordinary nets now), and every pass names
the nets it may not touch (`ignoreNets`) as well as the ones it may
(`onlyNets`); `onlyNets` alone did not hold against the recovery.

**The core rail and the PSRAM's 1.8 V are drawn too** (same file, C-54,
C-56). Mazed by the router, `VDD_HP` took 85 mm and six vias and `3V3`
292 mm and thirty-six; the DSL cannot pour an island on L3 (its plane
regions are the whole board or nothing) and the shim draws only on L1
and L4. So `VDD_HP` is an L on L4, 0.8 mm wide (C-54), 8.3 mm from the chip's
centre (down the left side from pin 54 past pin 76, along the bottom to
pin 91), with a 0.127 mm spur from each pin's escape via (2 mm between
the neighbouring vias, 125 mA each; the pitch allows nothing wider), a
via down to `L2`'s output pad and an L1 run from there to `C27`; pin 26 reaches it on L3 by the router, because
a right leg would have walled every right-side escape on L4 for one pin.
`1V8_PSRAM` joins its three left-side pins on a shorter L4 run inside the
L. The escapes those runs wall off leave on L3, which is what L3 is for.

Three more runs are drawn because the router took them the long way
round, measured on its own output: `VDD_HP`'s test point `TP11` is 25 mm
from the chip and got 180 mm of 0.8 mm track around the left and bottom
edges, so the L's bottom leg carries on east to a via 7 mm short of the
test point's column, and the router finishes from there; `VDD_FLASH` got
156 mm for `U8`, `R15` and `TP15`, so it leaves pin 30's via on L4 along
the top of the ring to a via at `U8` and one at `R15`, the test point
beyond being the router's; `I2C_SCL` got 115 mm for two pads 11 mm apart,
so it runs on L1 over the camera connector's upper row to its pull-up.
Each was 1.7 to 3.6 times the spread of its own pads. Drawn all the way to
both test points, with a right leg for pin 26, the runs walled L4 along
the whole right side and the router rolled a 45-minute pass back rather
than finish. A hand run stops where the router's own path was the
problem, not one millimetre further.

**The routing is freerouting's, through EasyEDA's own DSN export and
session import** (`layout/dsn_plane.py` before, `ses_clean.py`
after). The DSL router never got past 138 of 151 nets and rolled a
45-minute pass back to nothing; freerouting, given the same board, routed
it to a handful of open connections in twelve passes, with the plane
doing ground. What the export and the import get wrong is fixed in
those two files, not by hand, and the sequence is: board at hand copper
only, export, `dsn_plane.py`, freerouting (threads 1, Inner1 inactive,
Top and Bottom vertical, Inner2 horizontal), export session,
`ses_clean.py`, import the session, move Inner8 to Inner2, assemble the
vias `ses_clean.py` wrote through the shim, then the checks below. The
session quotes every net name but `GND`; a via placed as `"3V3"` sits on
a net of its own and joins nothing, and 184 of them did once.

**What freerouting leaves is finished against the artifact, not by eye.**
It stopped with `3V3` in three pieces, `I2C_SCL` and `HALOW_RST` in two,
and a dozen wires 3.5–4.8 mil from a pad. `net_islands.py` says which pads
sit in which piece; `hand_route.py` draws a link on L1/L4 through an A*
grid with every other net's copper inflated by its width and the
clearance, a via wherever one clears every layer, and measures the result
against the exact shapes before it goes on the board. The first version
looked at the outer layers only and put a via through an L3 wire. Two
escape vias it could not reach at all: their pocket on L4 is 1 × 2 mm,
walled by the `1V8_PSRAM` rail and the neighbouring escapes, which is the
same wall freerouting hit. Those links are drawn in the editor, where a
track can be pushed aside; a router that moves nothing cannot pass there.
Freerouting's ground (452 mm of L1 chaining between pads) is deleted:
the pours and the stitching grid (pass 3) do ground, and a ground stub
4 mil from a pad is a stub, not a design. Removing copper goes through
`clearRouting` on the whole net, and the extension is patched
(`tools/copilot-shim`) so the shim draws on L3 as well as L1 and L4;
the repair of one bad segment is therefore: copy the net's copper out of
the artifact, drop the segment, redraw it, clear the net, put the copy
back. Two of the sealed escapes opened that way, `I2C_SCL` leaving on
L3 where nothing else could.

**A hand-drawn width can be replaced without the copper moving.** The
session carried a 0.2 mm copy of a 0.127 mm escape stub; the copy landed
on top of the original and covered it, so the coverage check passed while
the wider track sat 0.0995 mm from two escape vias where the drawn one
had 0.136. `verify_hand_copper.py` now measures the width as well as the
path. Two stubs are still wider than drawn (`USB_DN_C`, `3V3`); both
clear 0.37 mm and stay, because a stub the router widened where there is
room is not the same defect as one widened in the channel.

**The ring capacitors' ground pads had no path, and the pours hid it.**
Under the left column L4 carries the `VDD_HP` trunk and L3 carried four
of freerouting's signals along the channel, so no via fitted beside or
under a pad; on L1 every ground pad sat between two escape exits.
Freerouting had left them open; the first pour then "connected" them
through islands that touched nothing, which is why island removal is on
for every plane and why the count to read after a pour is the DRC's, not
the picture's. `ring_ground.py` is the fix: `BOOT`, `SPI_SCK`,
`HALOW_WAKE`, `USB_DP`, `RXD0` and `FLASH_CK` are cleared, a 0.3/0.15 mm
via goes under each column capacitor straddling its ground pad, the top
row is stubbed to `C33`'s via, and the six nets come back around all of
it. Every other ground pad the DRC named gets a via with a stub, 0.6 mm
where it fits; the stitching grid itself is 0.6/0.3, not the DRC minimum,
because the P4's via floor is a floor for one package.

**Count the hand copper after every routing run.** The router rips
pre-existing copper as a "blocker" when a net will not route: its log
said `Ripped 1V8_PSRAM` of a run that then put tracks on a forbidden layer,
rolled back and applied nothing after 45 minutes. A run that *is* applied
may have done the same and kept it. The number to check is the track and
via count of the three hand files together, read back from the router's
input artifact, before anything else is judged; the hand copper is the
reproducible part of this board and a routing result is not.

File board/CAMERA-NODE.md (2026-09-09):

# Camera node — the board, before its schematic

**Status: circuit specification, drawn from [CAMERA-MESH.md](../CAMERA-MESH.md).
No part here is final until it has been picked from the library with its
datasheet open.** This is what the schematic is drawn *from*: the blocks,
the rails, the pin budget, the roles, and the decisions that are deliberately
left to draw time. It exists so the schematic answers a written question
instead of inventing one page by page, the same order the controller took
(CONTROLLER-V1 → LAYOUT-REQUIREMENTS → copper).

**The processor is the ESP32-P4, and that was the second choice.** The first
draft was an ESP32-S3 with an OV5640 on a parallel bus, which is the
ESP32-CAM class of picture: fine by day, poor by night. The S3 has no MIPI
receiver and no image processor, so the sensor's own tiny ISP is all the
picture gets. The market's night pictures come from a camera SoC with a
real ISP behind a 4–5 MP sensor; the P4 is that on a microcontroller's
sleep budget: MIPI CSI-2, a hardware ISP, JPEG and H.264 encoders, and a
12 µA deep sleep. It costs an external flash, a fine-pitch QFN on a
four-layer board, and a Wi-Fi companion for the base, because the P4 has
no radio. Those are written below, each with its reason.

---

## One board, three roles

The camera, the relay and the base are **one PCB, populated three ways**.
The P4 has no radio of its own, so the base's 2.4 GHz uplink to the
cabin's router is an **ESP32-C6 module on SDIO**, fitted only in the base
role (Espressif's own pairing, driven by their `esp_hosted` component). A
base is therefore a camera board with the sensor and flash left off and
the C6 and a microSD fitted. A relay is the same board with nothing but
the HaLow radio. One layout, one enclosure family, one firmware with a
role byte.

| Role | Populated | Not populated | Power |
|---|---|---|---|
| Camera | everything but the C6 | C6 | 1S cell, optional 2 W solar |
| Relay | MCU, radio, power, microSD | sensor, IR-cut, flash, pyro, C6 | 1S cell + 5 W solar |
| Base | MCU, radio, power, microSD, **C6** | sensor, IR-cut, flash, pyro | 12 V in through the same charger input, cell as hold-up |

---

## Rails

Everything about this board's battery life is decided here, so the rails
come before the blocks.

| Rail | Source | Who | Why it is its own rail |
|---|---|---|---|
| `VCELL` | 1S cell (LiFePO₄ 3.2 V or Li-ion 3.6 V nominal), through the charger's power path (`SYS`) | charger, boosts, ADC divider | The cell is the only thing that is always there |
| `3V3` | Ultra-low-quiescent buck from `SYS` (TPS62840: ~60 nA quiescent, 750 mA); its enable is the slide switch's OFF position | P4 (its own domains, listed below), flash, pyro, the C6 in the base role | This rail is on for years. Its quiescent current *is* the sleep budget. OFF kills it and everything downstream, and leaves the charger alive so a camera in a drawer by a window still charges |
| `VDD_HP` | 1.1 V buck the **P4 controls itself** (`EN_DCDC`, `FB_DCDC` into a TLV62569) | P4 core | The chip turns it off in deep sleep and trims it under load; an external buck is what Espressif's reference does, and the internal core LDO exists only as a fallback |
| `1V8_PSRAM`, `2V5_MIPI`, `VDD_FLASH` | The P4's own output LDOs (`VDDO_PSRAM`, `VDDO_3`, `VDDO_FLASH`), each with its capacitors | in-package PSRAM, MIPI D-PHY, the flash | Rails we decouple rather than make. All three die in deep sleep with the HP domain, which is why the flash needs no switch |
| `3V3_HP` | **Buck-boost** from `SYS` (TPS63021, fixed 3.3 V, 2 A), enabled by a GPIO | the three switched rails below | A cold cell under a one-amp burst sags below a buck's dropout; a buck-boost holds 3.3 V down to a 2.5 V cell. Off in sleep, ~1 µA |
| `3V3_CAM` | Load switch from `3V3_HP` (TPS22917) | camera module, IR-cut driver, ambient-light sensor | The sensor leaks hundreds of µA in "standby". Cutting the rail is the only real off |
| `3V3_RF` | Load switch from `3V3_HP` | HaLow module (up to ~400 mA in transmit) | Same reason. A radio module's sleep current is a datasheet number; a load switch is a measurement |
| `3V3_SD` | Load switch from `3V3_HP` | microSD | An idle card draws 100–200 µA. It is used by both the camera and the radio, so it gets its own switch |
| `VLED` | Boost from `SYS` (TPS61165 class, EN/PWM from the MCU) | 8–12 × 850 nm LEDs in strings, current-sense shunt | Enabled only during exposure, tens of milliseconds per picture. Never idles |
| `VUSB` | USB-C, 5 V | charger input, programming | The lesson of board A: a first image needs a wire the board actually exposes |

**Why two bucks and not one.** The always-on `3V3` buck is chosen for
its quiescent current and gives 750 mA. Awake, the board can ask for more
than that at once: the P4 (~100 mA from 3.3 V), a camera module (150–200
mA), a microSD writing (up to 200 mA) and a HaLow module transmitting
(300–400 mA). A rail that only stays inside its budget because the
firmware promises never to write a card during a transmit is a rail that
browns out the day the promise is broken. So the awake loads hang off
their own converter, and the sleep converter never sees them.

**Sleep target: under 30 µA** total with the cell at nominal: P4 deep
sleep 12 µA by the datasheet, `3V3` buck quiescent, pyro standby, the
buck-boost and three load switches disabled, the core buck disabled by
the chip, the divider switched off. This is a measurement before it is a
claim; the first board carries a jumper in the cell lead for exactly that
meter.

**Charger.** 1S, solar-tolerant input (5–6 V panel or 12 V through a
pre-regulator in the base role), **programmable termination** so one board
serves LiFePO₄ (3.6 V) and Li-ion (4.2 V) by a resistor, **power path** so a
flat cell in sunlight still boots the node, and an **NTC input that stops
charging below 0 °C**. The controller's frost rule, in a chip. Lithium
primary AA cells (the −40 °C option) are a later variant with a different
input, not this board.

---

## Blocks

Grouped by completed function, which is also how the schematic pages split.

### MCU

**ESP32-P4NRW32**: dual-core RISC-V at 400 MHz, **32 MB PSRAM in the
package** (a 5 MP frame and its JPEG both fit, with room for the ISP's
buffers), MIPI CSI-2, hardware ISP, JPEG and H.264. It needs an
**external 16 MB QSPI flash** on its dedicated flash pins, a **40 MHz
crystal**, a **32.768 kHz crystal** on GPIO0/GPIO1 (the wake schedule in
[CAMERA-MESH.md](../CAMERA-MESH.md) assumes ±20 ppm; the internal RC is
±5 %), and its core buck. USB Serial/JTAG on GPIO24/25 through a USB-C
with ESD is the programmer and the console; the high-speed USB pins stay
unused. Boot and reset buttons, one status LED, test points on every rail,
on UART0 and on the four JTAG pins.

The pin map below is copied from Espressif's ESP32-P4-Function-EV-Board
wherever the choice was free, so the dev kit's firmware runs on this board
without a pin table edit. Where it departs, the row says why.

### Camera

**MIPI CSI-2 camera on the Raspberry Pi 15-pin 1.0 mm FPC**, the connector
Espressif's own board uses and the one every Pi camera and its clones fit.
The module carries its own regulators and its own 24 MHz oscillator (the
15-pin standard has no XCLK), so the connector supplies only 3.3 V, I²C,
and two GPIO. Changing the sensor is changing the module, not the board.

**What may go on the end of that flex is decided by Espressif's driver
list, not by the sensor market.** `esp_cam_sensor` carries OV5647, SC2336,
OV5640, OV02C10 and a handful of others; there is no IMX219, IMX477 or
IMX708 driver, so a Pi Camera v2 or v3 will not enumerate whatever its
datasheet promises. That leaves **OV5647** as the only sensor sold on
15-pin boards, and its driver's **1280×960 binning mode** is the one to
use at night: summing the 1.4 µm pixels four at a time is worth more in
the dark than the 5 MP the part number advertises. SC2336 would be the
better sensor (2.7 µm, built for security cameras), but nobody sells it
on a 15-pin board, only on Espressif's 24-pin. The bench comparison the
gates ask for is therefore OV5647 binned against OV5647 unbinned, not one
sensor against another.

**Why not the sensor on the board, the way the mass-market cameras do it.**
Theirs is a bare die on the main board under a lens holder that a jig
focuses on the line, by the thousand. A five-board run has no jig: a lens
holder glued and focused by hand is a soft picture, and it is the picture
a hunter judges. A module arrives with its lens focused at the factory,
its filter glued flat, and its own regulators, and JLC stocks none of the
bare sensors anyway. The connector costs a dollar and a ZIF latch; what
it buys is a sharp first picture and a sensor swap without a board spin.
Sensor-on-board is the cost-down for the day a run is large enough to
own a focus jig. The CSI wiring to the P4 does not change.

**Mechanical IR-cut filter**, and the board drives it two ways because
modules split two ways. A bare actuator gets the H-bridge (two GPIO, one
pulse each way; DRV8837) out to its own two-pin connector. A Pi-style
module (Arducam's and Waveshare's IR-CUT boards) has the driver on it
already and switches on a level held on the connector's **pin 12**, the
line the Pi calls the camera LED; that pin is `CAM_IO1`, wired to the P4,
so those modules need no board change and leave the H-bridge unused.
**Ambient-light sensor** (phototransistor on an ADC pin) decides day/night
for the filter and the flash without waking the sensor.

### Trigger

**Digital pyroelectric sensor** (Excelitas PYD 1598: serial interface,
on-chip threshold, ~3 µA) behind a Fresnel lens in the housing tuned to
the field of view. Its direct-link line lands on a **low-power-domain
GPIO** (GPIO0–15 on the P4) so the MCU sleeps through everything but a
real crossing; its serial-in line takes one more pin. LCSC does not
stock it, but JLCPCB's own catalogue lists it as **C3678555**, a
pre-order part, wave-soldered like any through-hole part, held in the
account's parts library for the assemblies that follow. So it is
assembled like everything else, after one pre-order. The analog
alternative (a D203S element and a BISS0001, both at LCSC) is a
different sleep budget, not a fallback: the element's bias and the
BISS0001 together draw 40–60 µA, twice the whole node's target. If the
digital part ever becomes unobtainable, that is a page revision, not a
resistor swap.

### Flash

One string of ten 850 nm LEDs on a boost driver, a **current-sense
shunt**, which the teardown found, read on an ADC pin so the firmware
knows a black night picture came from a dead string and not from the
sensor, one control line from the MCU that is both enable and PWM,
exposure-synchronous. The first board's string is ten small 3528 parts
at 150 mA (about 2 W), enough to prove the pipeline and not enough to
light a moose at 20 m. The class's answer to that is a **second board in
the lid**: the LED array, and often the pyro and the light sensor with
it, sit on a front board behind the window with a flex to the main board
in the body, because those three parts must face the scene and the main
board must sit against the battery. This node will do the same the day
the housing is drawn: the flash driver stays on the main board, the
string and the pyro move to the front board, and the two connectors
appear on these pages. The nets do not change.

### Radio

**HaLow module — decided: Quectel FGH100M (FGH100MABMD)**, a Morse
Micro MM6108 in a 13 × 13 mm LGA. The range test was going to pick
between the MM6108 and Newracom's NRC7394; the decision came earlier and
on other grounds: LCSC and JLC assemble no Newracom module at all, the
MM6108 is the silicon every serious HaLow product ships, and Morse
Micro's **official ESP-IDF component lists the ESP32-P4 as a tested
host** with AP mode available for the base. Of Quectel's two variants
the plain FGH100M is the one certified for **Canada (IC), FCC and CE**
today at 21 dBm; the `-H` variant reaches 27 dBm through a 5 V front-end
but is preliminary, FCC "planned" only, and on a different footprint, so
it is not a drop-in later. The receiver is the number that matters at
the ranges the mesh uses: −109 dBm at MCS10 in a 1 MHz channel.

The driver wants eight lines, and the schematic gives it eight on the
P4's IO-MUX SPI pins: `SPI_SCK`, `SPI_MOSI`, `SPI_MISO`, `HALOW_CS`,
`HALOW_IRQ` (out-of-band data-ready), `HALOW_BUSY` (rising-edge
interrupt, needed for power save), `HALOW_WAKE` (the module's
`WAKEUP_IN`) and `HALOW_RST` (`RESET_N`, held low by 10 k so the module
sleeps at ~0 µA until the P4 releases it). The pad assignment comes from
Seeed's published schematic of the same module (their XIAO HaLow hat,
FGH100M-H): `SDIO_CLK` is the SPI clock, `SDIO_CMD` MOSI, `SDIO_DATA0`
MISO, `SDIO_DATA3` chip select with 47 k up, `SDIO_DATA1` the interrupt,
`GPIO0` BUSY, 22 Ω in series with clock and data, and 10 k to ground on
`GPIO1`–`GPIO9` and the four JTAG inputs. The module runs from `3V3_RF`
through its switch; `VDD_FEM` reaches that rail through a 0 Ω link,
because the `-H` brief gives that pin its own 3–5.25 V supply and the
plain brief says nothing. Antenna pad through 0 Ω to the U.FL, with two
unpopulated shunt pads for a matching network the bench may never need.

**ESP32-C6-MINI-1, base role only**, on the P4's second SDIO slot with
the six 51 k pull-ups Espressif specifies, its enable and boot pin on P4
GPIOs, and its UART0 crossed to the P4's UART1 so the P4 can put it in
download mode and flash it. No second cable for the second chip.

### Storage

microSD on **4-bit SDMMC** (the P4's slot 1, on its IO-MUX pins). The
camera's own copy of every full frame; the base's ring buffer. Its rail is
switched, its card-detect is read, its six lines carry the 51 k pull-ups
the SD specification asks for and a TVS each, because the card is the one
thing a gloved hand touches in January. **microSD, not full-size SD, by
decision:** the mass-market cameras fit a full-size slot because the hunter
comes to read the card; here the card is the archive the base empties over
the radio, and the smaller socket saves 20 mm of board.

---

## Pin map

The S3 draft did not close its pin budget and closed it with an I²C
expander. The P4 has 55 GPIO and needs none, which also removes a trap:
that expander powers up with every output **high**, so the rail enables
on it would have switched every rail on at each boot. On the P4 every
enable is a chip pin that is high-impedance at reset, held low by its own
pull-down.

| GPIO (pin) | Signal | Why this pin |
|---|---|---|
| GPIO0 (104), GPIO1 (1) | `XTAL_32K_N`, `XTAL_32K_P` | the only 32 kHz crystal pins on the P4 |
| GPIO2 (2) | `MTCK` | the last JTAG pin, on a test point. The other three went to the setup switch, the pyro and the radio; USB Serial/JTAG is the debugger, and it needs none of them |
| GPIO3 (3) | `HALOW_BUSY` | the HaLow module's BUSY line, a rising-edge interrupt the driver needs for power-save mode; without it the radio never sleeps |
| GPIO5 (5) | `PIR_SI` | the pyro's serial-in configuration line. It was `MTDO`, a chip output under JTAG, so an attached debugger would write nonsense into the pyro's registers (while debugging, and only then) |
| GPIO4 (4) | `SETUP_SW` | the slide switch's SETUP position, on a low-power-domain pin so moving the switch wakes the node. It was `MTMS`; a debugger drives that pin push-pull and wins over the 100 k pull-up, so JTAG still works. Only in SETUP position would the reading be nonsense, which nobody debugging cares about |
| GPIO6 (6) | `PIR_WAKE` | low-power domain: wakes the chip from deep sleep |
| GPIO7 (7), GPIO8 (8) | `I2C_SDA`, `I2C_SCL` | the dev kit's I²C; the camera module's SCCB rides it |
| GPIO9 (10) | `C6_WAKEUP` | base only |
| GPIO10 (11), GPIO11 (12) | `C6_U0RXD`, `C6_U0TXD` | UART1 on its IO-MUX pins, crossed to the C6's UART0 for flashing it. Base only |
| GPIO12 (13), GPIO13 (14) | `C6_EN`, `C6_IO9` | the C6's enable and boot strap, driven by the P4. Base only |
| GPIO14–17 (15–18) | `SD2_D0`–`SD2_D3` | SDIO slot 2 to the C6, as the dev kit wires it. Base only |
| GPIO18 (19), GPIO19 (20) | `SD2_CLK`, `SD2_CMD` | |
| GPIO20 (22) | `ADC_LIGHT` | ADC1 channel 4 |
| GPIO21 (23) | `ADC_VCELL` | ADC1 channel 5 |
| GPIO22 (24) | `ADC_FLASH_I` | ADC1 channel 6: the flash shunt |
| GPIO23 (25) | `VCELL_SENSE_EN` | |
| GPIO24 (52), GPIO25 (53) | `USB_DN`, `USB_DP` | USB Serial/JTAG, through 33 Ω as the dev kit does |
| GPIO26 (55) | `LED_STATUS` | |
| GPIO27 (56) | `EN_3V3_HP` | the buck-boost's enable |
| GPIO28–31 (57, 58, 60, 61) | `HALOW_CS`, `SPI_MOSI`, `SPI_SCK`, `SPI_MISO` | SPI2 on its IO-MUX pins: no GPIO-matrix latency on the radio's bus |
| GPIO32 (63), GPIO33 (64) | `HALOW_IRQ`, `HALOW_RST` | |
| GPIO34 (65) | `STRAP_JTAG` | strapping pin the datasheet forbids leaving floating: 10 k to ground, test point, nothing else |
| GPIO35 (66) | `BOOT` | strapping: 10 k up, button to ground |
| GPIO36 (68) | `HALOW_WAKE` | the module's `WAKEUP_IN`; a strapping pin that only selects ROM printing, and only when an eFuse is burnt; 100 k down gives it a level at reset |
| GPIO37 (69), GPIO38 (70) | `TXD0`, `RXD0` | UART0 on test points |
| GPIO39–42 (80–83) | `SD1_D0`–`SD1_D3` | SDMMC slot 1 on its IO-MUX pins, the microSD |
| GPIO43 (84), GPIO44 (86) | `SD1_CLK`, `SD1_CMD` | |
| GPIO45 (87) | `EN_3V3_SD` | |
| GPIO46 (88) | `SD_DET` | |
| GPIO47 (89), GPIO48 (90) | `EN_3V3_CAM`, `EN_3V3_RF` | |
| GPIO49 (92), GPIO50 (93) | `CAM_IO0`, `CAM_IO1` | the Pi connector's two GPIO: enable/reset, and a strobe most modules leave unconnected |
| GPIO51 (94), GPIO52 (95) | `ICR_A`, `ICR_B` | the IR-cut H-bridge |
| GPIO53 (97) | `CHG_STAT1` | the charger's "charging" line; its second status line stays on a pull-up, and `CE#` stays tied low because the charger's own NTC rule is the only gate the cell needs |
| GPIO54 (98) | `FLASH_CTRL` | one pin: the boost driver's enable *is* its PWM input (TPS61165 class) |

Dedicated pins: the flash on 27–33, CSI on 42–48 with its 4.02 k
reference resistor, DSI 34–40 left open, high-speed USB 49–50 left open
with its PHY still powered as the datasheet requires.

Every microcontroller pin is now assigned once. Nothing is shared by
wishful thinking, and nothing is on an expander.

## Schematic pages

| Page | Holds |
|---|---|
| 1 MCU | P4 and its decoupling, core buck, both crystals, flash, USB-C + ESD, boot/reset, strapping, status LED, JTAG/UART test points |
| 2 Power | cell, charger, solar/USB input, `3V3` buck and the OFF/SETUP/ON switch on its enable, `3V3_HP` buck-boost, the three load switches, NTC, cell divider, the sleep-current jumper |
| 3 Camera | 15-pin CSI FPC, IR-cut H-bridge, ambient-light sensor |
| 4 Trigger | pyro, its wake line, footprint reserve for the analog fallback |
| 5 Flash | boost driver, LED strings, shunt |
| 6 Radio | the FGH100M HaLow module with its series resistors, straps and decoupling, the U.FL, the C6 companion and its SDIO |
| 7 Storage | microSD on SDMMC, its pull-ups, its TVS, card detect |

There is no role header: the role byte lives in flash and is set over
the same USB-C that flashes the firmware.

---

## What the hand gets

Three things a person touches in the field, and one they see. All three
sit behind **one gasketed door**, the way the class does it, so the sealed
part of the housing is never opened outdoors:

- **The slide switch, OFF / SETUP / ON.** On the `3V3` buck's enable,
  where it switches microamps, rather than in the cell lead, where a
  contact carrying one-amp bursts ages. OFF: the buck and everything
  below it are dead, ~0.15 µA, and the charger still charges. SETUP:
  pulls `SETUP_SW` low, which wakes the P4 and puts it in pairing and
  set-up mode. ON: nothing pulled, the node runs its schedule.
- **The microSD**, push-push, with its TVS array.
- **The USB-C**, which is the **service port**. The P4's USB Serial/JTAG
  is behind it with no other part: `esptool` puts the chip in download
  mode by itself over that port, so **flashing needs no BOOT button**.
  The button is for the bench. The same port is the console and the
  configuration channel. The base's C6 is flashed *through* the P4 (its
  boot pin, enable and UART0 are on P4 pins, the way Espressif's
  `esp_hosted` expects), and the HaLow module carries no firmware of its
  own: the P4 loads it over SPI at every boot. One cable, every chip.
  Field updates over HaLow come later and change nothing here.

The thing they see is the **antenna**: a U.FL on the board to a 900 MHz
whip on an IP67 RP-SMA bulkhead through the housing. A whip on top of a
plastic box beats a PCB antenna inside it by 3–6 dB and can be pointed;
on the base it goes up a mast. The pigtail is a housing part, kept short.
The base's C6 keeps its module antenna: it talks to a router ten metres
away, indoors.

---

## What the weather gets

The teardown showed a bare board with hand-soldered flying leads
and no coating, in a gasketed box. A sealed box that cycles between −30
and +25 °C breathes through its gasket and condenses inside; that is how
trail cameras die: corrosion at the battery contacts and the microphone
port. Three rules, none expensive:

- **Conformal coating** on every populated board (acrylic, sprayed after
  assembly with the connectors masked; JLC does not offer it, the bench
  does). The controller's board A is uncoated because it lives indoors; a
  board on a tree is not allowed that argument.
- **A pressure-equalising vent membrane** in the housing, so the air
  inside follows the outside without carrying water. A desiccant sachet
  is the consumer answer and lasts one season.
- **No flying leads.** Everything leaves the board on a connector or an
  FFC, the same KF2EDG/JST family as the controller.

## Decided at draw time, with the datasheet open

Named here so nobody mistakes a placeholder for a choice. Decided ones
carry their numbers and the LCSC stock seen on the day, because a part
with 183 units is a prototype part, not a production one.

1. **Charger — decided: BQ25185DLHR** (LCSC C19725033, WSON-10, **183 in
   stock on 2026-09-02; fine for prototypes, re-check before any run**).
   3.6–18 V in, 25 V tolerant, so the panel and a 12 V base feed IN
   directly through a Schottky each. `ILIM/VSET` = **18 kΩ → 4.2 V /
   500 mA input limit** (Li-ion); **3.6 kΩ → 3.6 V** for LiFePO₄. One
   resistor, the only change between chemistries. `ISET` = **1 kΩ → 300 mA**
   (I = 300 AΩ / R). `TS/MR`: a bare **10 kΩ NTC to ground**. The pin's
   38 µA bias puts the cold trip at 1.0 V ≈ 0 °C and hot at 0.115 V ≈
   60 °C by itself (the datasheet's curve is β 3435; the NCP18XH103 is
   3380, close enough for a charge cutoff). Power path regulates SYS at
   4.5 V; both bucks run from SYS. `CE#` pulled down (charging on);
   `STAT1/2` open-drain with 10 k pull-ups. IN and SYS capacitors 25 V
   rated as TI asks: 1 µF 0603 (CL10B105KA8NNNC, C29936, 1.8 M in stock;
   the first pick, CL10A105KB8NNNC, showed **zero stock** and was dropped)
   and 10 µF 0805 (CL21A106KAYNNNE, C15850).
2. **`3V3` buck — decided: TPS62840DLCR** (C2071859, VSON-8, 6 440 in
   stock). 1.8–6.5 V in, 750 mA, 60 nA quiescent. `VSET` = **267 kΩ →
   3.3 V** (E96, Table 1 of the datasheet), `MODE` and `STOP` to ground,
   `EN` to SYS. Inductor the one TI characterises: **DFE201612E-2R2M**
   2.2 µH 0806 (C337893, 13 k in stock); 10 µF in and out.
3. **Load switches — decided: TPS22917DBVR** (C2681320, SOT-23-6, 19 840
   in stock) instead of the TPS22916 first named: that one only comes in
   a 0.7 mm DSBGA, which is a yield problem on a first board. 2 A, `QOD`
   tied to `VOUT` so each rail is actively discharged when off, `CT` left
   open, `ON` held low by 100 k so a rail is off until the firmware says
   otherwise. Three of them: camera, radio, card.
4. **Cell sense:** 100 k/100 k divider on `ADC_VCELL`, its top switched by a
   P-MOSFET (SI2301, C10487) whose gate a 2N7002 (C8545) pulls down from
   `VCELL_SENSE_EN`; 100 k pull-down keeps it off at reset. Off, the
   divider draws nothing.
5. **Processor — decided: ESP32-P4NRW32** (C22387510, QFN-104 10 × 10 mm,
   0.35 mm pitch, **zero stock at LCSC on 2026-09-02, $5.92**; ordered
   through JLC's sourcing before the board, or bought and consigned; the
   first bench unit is an ESP32-P4-Function-EV-Board, not this PCB). The
   board becomes **four layers**: the D-PHY pairs and the 0.35 mm QFN
   need it, and the controller's two-layer rules do not carry.
6. **Core buck — decided: TLV62569DBVR** (C141836, SOT-23-5, 122 k in
   stock), the part on Espressif's own board, wired exactly as they do:
   `EN` from the P4's `EN_DCDC`, `FB` from its `FB_DCDC`, 2.2 µH
   (DFE201612E-2R2M again), 4.7 µF in, 22 µF out (CL21A226MQQNNNE, C5674).
   The chip owns the feedback; there is no divider to get wrong.
7. **`3V3_HP` buck-boost — decided: TPS63021DSJR** (C202140, VSON-14,
   2 297 in stock, $3.29; the one expensive part, and the one that keeps
   a −20 °C cell from browning out the radio). Fixed 3.3 V, 2 A, `EN` from
   `EN_3V3_HP` with 100 k down, `PS/SYNC` low for power-save mode. Inductor
   1.5 µH rated 3 A; picked with its saturation curve, below.
8. **Flash — decided: W25Q128JVSIQ** (C97521, SOIC-8, **Basic part**,
   34 k in stock) on the P4's dedicated flash pins, powered by the chip's
   own `VDDO_FLASH`, `/CS` pulled up 10 k as the reference does.
9. **Camera connector — decided: TE 1-1734248-5** (C2922285, 15-pin
   1.0 mm bottom-contact FPC, 948 in stock), the exact part on the
   Function-EV board so the flex orientation is not a guess. Pinout is the
   Raspberry Pi's: GND / D0− / D0+ / GND / D1− / D1+ / GND / CLK− / CLK+ /
   GND / IO0 / IO1 / SCL / SDA / 3V3. `IO0` pulled up 10 k, I²C pulled up
   2.2 k on the camera side of the 0 Ω links, 4.02 k `CSI_REXT` to ground,
   and **100 Ω in series with each of the six lane wires** because the
   reference board has them and a MIPI lane is the one interface on this
   board nobody can probe on a bench.
10. **Wi-Fi companion, base only — decided: ESP32-C6-MINI-1-N4**
    (C5736265, 559 in stock). SDIO slot 2 with 51 k pull-ups on the six
    lines, `EN` 10 k up with 1 µF, `IO8` 10 k up (its strap), `IO9` and
    UART0 to the P4.
11. **IR-cut driver — decided: DRV8837DSGR** (C39159, WSON-8), on
    `3V3_CAM`, `nSLEEP` tied to that rail; 2-pin JST PH to the filter.
    **Ambient light — decided: ALS-PT19-315C** (C146233, 575 in stock),
    collector on `3V3_CAM`, 100 k emitter load, so it draws nothing in
    sleep and cannot read while the camera rail is off, which is the
    order the firmware wants anyway.
12. **Slide switch — decided: SS13D07VG4** (C2681578, 1P3T through-hole,
    17 k in stock), through-hole on purpose so a gloved thumb cannot
    lift it off the board. Its four terminals sit in a row and the
    slider bridges two neighbours per position, so pin 2 is ground, pin 1
    is the buck enable (OFF), pin 3 is `SETUP_SW` (SETUP) and pin 4 is
    open (ON); `BUCK_EN` has 100 k to `SYS`, `SETUP_SW` 100 k to `3V3`
    and 100 nF for the bounce. **Confirm the bridging order on the
    datasheet before the board**. A single-common variant with the
    common on pin 1 would tie the enable to the setup line.
13. **microSD — decided: TF-01A** (C91145, push-push, 81 k in stock),
    51 k pull-ups on D0–D3 and CMD to `3V3_SD`, `SD_DET` 100 k to `3V3`,
    and a **BSDFN2C031U** TVS (C600818, DFN1006, 9.8 k in stock) on each
    of the six lines, the part on Espressif's board, one per line
    because six singles route next to a socket where a four-channel
    array does not.
14. **Antenna — decided: U.FL-R-SMT-1(80)** (C88374, Hirose, 58 k in
    stock) to an RP-SMA bulkhead with an O-ring; the bulkhead and the
    pigtail are housing parts. The HaLow module is drawn as a **1×10
    2.54 mm header** (PZ254V-11-10P, C492409) carrying `3V3_RF`, ground,
    the SPI, `HALOW_CS`, `HALOW_IRQ`, `HALOW_RST` and `HALOW_EN`. That is the
    footprint a dev module plugs into for the range test, replaced by the
    module's own once it is chosen.
15. **LED driver — decided: TPS61165DBVR** (C58756, SOT-23-6, 24 k in
    stock), with its datasheet open: 3–18 V in, 38 V open-LED
    protection, 200 mV feedback, `CTRL` is enable, PWM and one-wire
    dimming on one pin with an internal 800 k pull-down (off at reset,
    1 µA shut down), `COMP` wants 220 nF, 10 µH in, 1–10 µF out. Fed from
    `SYS`. Shunt **1.33 Ω → 150 mA** (RTT051R33FTP, C158243, 44 k in
    stock), which is what the chip's 1.2 A switch delivers into a 15 V
    string from a 3.3 V cell (Figure 1 of the datasheet), and read on
    `ADC_FLASH_I` through 1 k / 10 nF. Output capacitor 4.7 µF **50 V**
    1206 (12065C475K4Z2A, C779997) because the open-LED clamp is 38 V.
    Inductor CY54-10UH (C2929431, 5.8 × 5.2 mm, 31 k in stock). Confirm
    its saturation current is above 1.2 A on the datasheet. LEDs
    JNJ-L-3528CW-85020D (C22447917, 850 nm, 20°, 2 000 in stock): the
    3535 one-watt parts LCSC lists had 1 to 170 units each, which is not
    a production part; the front board picks its own.
16. **Pyro — decided: Excelitas PYD 1598 / 7655** (JLCPCB C3678555,
    TO-5 4-lead, **zero in stock, pre-order at ~$5.72 in quantity, two
    minimum**, wave-soldered, kept in the account's parts library), drawn
    with its own symbol: Direct Link → `PIR_WAKE`, Serial In → `PIR_SI`,
    supply through 100 Ω / 10 µF from `3V3`. See the Trigger block for
    why the LCSC analog path is not a fallback.
17. **HaLow module — decided: Quectel FGH100MABMD** (C23509203, LGA
    13 × 13 mm, **44 in stock, $13.15**; the `-H` is C53961956, 6 in
    stock, preliminary, different footprint). Rails: `VBAT` 3.0–3.6 V and
    `VDDIO` from `3V3_RF`; `VDD_FEM` tied to the same rail pending the
    hardware design guide (the `-H` brief gives it 3.0–5.25 V, the plain
    brief does not list it). Host lines as in the Radio block. **The
    SPI-mode pad assignment (which SDIO pads are SCK/MOSI/MISO/CS, which
    pad is the SPI IRQ, which GPIO is BUSY) is confirmed against
    Quectel's FGH100M Hardware Design before layout**. It is the one
    document this page was drawn without, and it is behind Quectel's
    registration wall, not LCSC's.
18. The 40 MHz crystal and the buck-boost inductor: picked from stock at
    draw time; the crystal must be −40 °C rated with a load capacitance
    the two 22 pF (or the pair the part's own CL asks for) match.
19. **The P4's pin capacitors are 0402, decided at layout**: 100 nF
    C1525, 1 µF C52923, 10 nF C15195, 22 pF C1555. Samsung and FH,
    all JLC basic parts, millions in stock. A side of the 0.35 mm QFN is
    10 mm and holds six 0603 parts; its left side has eight supply pins
    on six nets, and with 0603 parts two of them had no capacitor within
    7 mm. The 10 µF, 4.7 µF and 22 µF bulk parts stay 0603/0805: a 10 µF
    0402 is a 6.3 V part that keeps half its capacitance at 3.3 V.
    [CAMERA-LAYOUT.md](CAMERA-LAYOUT.md) C-35 holds the distances.

## Measured before the board is believed

Sleep current through the jumper, at room temperature and in a freezer.
Trigger-to-first-frame from deep sleep. Flash exposure energy per picture.
**And now a fourth, first:** a night picture at 15 m with an 850 nm flash,
from the Function-EV board with an OV5647 NoIR, next to the same scene
from an ESP32-S3 with an OV5640. That is the picture that justified this
page's second draft, taken before the PCB exists. All four sit in
[CAMERA-MESH.md](../CAMERA-MESH.md)'s list of conditions; this board is where
the numbers come from.

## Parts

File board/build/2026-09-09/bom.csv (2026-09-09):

No. | Quantity | Comment | Designator | Footprint | Value | Manufacturer Part | Manufacturer | Supplier Part | Supplier
1 | 16 | 10uF | C1,C9,C10,C11,C12,C15,C18,C23,C42,C44,C51,C53,C56,C59,C65,C66 | C0603 | 10uF | CL10A106KP8NNNC | SAMSUNG(三星) | C19702 | LCSC
2 | 16 | 100nF | C2,C3,C4,C5,C14,C16,C17,C19,C21,C24,C25,C26,C29,C31,C34,C41 | C0402 | 100nF | CL05B104KO5NNNC | SAMSUNG(三星) | C1525 | LCSC
3 | 3 | 1uF | C6,C8,C55 | C0603 | 1uF | CL10B105KA8NNNC | SAMSUNG(三星) | C29936 | LCSC
4 | 3 | 10uF | C7,C47,C63 | C0805 | 10uF | CL21A106KAYNNNE | SAMSUNG(三星) | C15850 | LCSC
5 | 10 | 100nF | C13,C43,C45,C46,C50,C52,C54,C57,C58,C60 | C0603 | 100nF | CL10B104KB8NNNC | SAMSUNG(三星) | C1591 | LCSC
6 | 2 | 4.7uF | C20,C36 | C0603 | 4.7uF | CL10A475KQ8NNNC | SAMSUNG(三星) | C8032 | LCSC
7 | 2 | 10nF | C22,C32 | C0402 | 10nF | CL05B103KB5NNNC | SAMSUNG(三星) | C15195 | LCSC
8 | 3 | 22uF | C27,C48,C49 | C0805 | 22uF | CL21A226MQQNNNE | SAMSUNG(三星) | C5674 | LCSC
9 | 4 | 1uF | C28,C30,C33,C35 | C0402 | 1uF | CL05A105KA5NQNC | SAMSUNG(三星) | C52923 | LCSC
10 | 4 | 22pF | C37,C38,C39,C40 | C0402 | 22pF | 0402CG220J500NT | FH(风华) | C1555 | LCSC
11 | 1 | 220nF | C61 | C0603 | 220nF | CL10B224KB8NNNC | SAMSUNG(三星) | C64705 | LCSC
12 | 1 | 4.7uF | C62 | C1206 | 4.7uF | 12065C475K4Z2A | Kyocera AVX | C779997 | LCSC
13 | 1 | 10nF | C64 | C0603 | 10nF | 0603B103K500NT | FH(风华) | C57112 | LCSC
14 | 1 | USBLC6-2SC6 | D1 | SOT-23-6_L2.9-W1.6-P0.95-LS2.8-BL |  | USBLC6-2SC6 | ST(意法半导体) | C7519 | LCSC
15 | 3 | B5819W | D2,D3,D11 | SOD-123_L2.7-W1.7-LS3.8-RD |  | B5819W | 晶导微电子 | C2685454 | LCSC
16 | 1 | D-060306G1/SS2/G1 | D4 | LED0603-RD |  | D-060306G1/SS2/G1 | ARKLED(方舟) | C118334 | LCSC
17 | 6 | BSDFN2C031U | D5,D6,D7,D8,D9,D10 | DFN1006-2L-BI |  | BSDFN2C031U | BORN(伯恩半导体) | C600818 | LCSC
18 | 10 | JNJ-L-3528CW-85020D-S-J2 | D12,D13,D14,D15,D16,D17,D18,D19,D20,D21 | LED-SMD_L3.5-W2.8-L-FD |  | JNJ-L-3528CW-85020D-S-J2 | JNJOPTO(强生光电) | C22447917 | LCSC
19 | 1 | TYPE-C-31-M-12 | J1 | USB-C_SMD-TYPE-C-31-M-12_1 |  | TYPE-C-31-M-12 | 韩国韩荣 | C165948 | LCSC
20 | 3 | B2B-PH-K-S(LF)(SN) | J2,J3,J5 | CONN-TH_B2B-PH-K-S |  | B2B-PH-K-S(LF)(SN) | JST | C131337 | LCSC
21 | 1 | 1-1734248-5 | J4 | CONN-SMD_1-1734248-5 |  | 1-1734248-5 | TE Connectivity(泰科电子) | C2922285 | LCSC
22 | 1 | TF-01A | J6 | TF-SMD_TF-01A |  | TF-01A | 韩国韩荣 | C91145 | LCSC
23 | 1 | 6GHz | J8 | RF-SMD_FRF05002-JSS103M | 6GHz | U.FL-R-SMT-1(80) | HRS(广濑) | C88374 | LCSC
24 | 1 | PZ254V-11-02P | JP1 | HDR-TH_2P-P2.54-V-M |  | PZ254V-11-02P | XFCN(兴飞) | C492401 | LCSC
25 | 2 | 2.2uH | L1,L2 | L0806 | 2.2uH | DFE201612E-2R2M=P2 | muRata(村田) | C337893 | LCSC
26 | 1 | CKCSA4020-1.5uH/N | L3 | IND-SMD_L4.0-W4.0 |  | CKCSA4020-1.5uH/N | CENKER(岑科) | C5442006 | LCSC
27 | 1 | CY54-10UH | L4 | IND-SMD_L5.8-W5.2 |  | CY54-10UH | SHOU HAN(首韩) | C2929431 | LCSC
28 | 1 | SI2301CDS-T1-GE3 | Q1 | SOT-23-3_L3.0-W1.7-P0.95-LS2.9-BR |  | SI2301CDS-T1-GE3 | VISHAY(威世) | C10487 | LCSC
29 | 1 | 2N7002 | Q2 | SOT-23-3_L2.9-W1.3-P1.90-LS2.4-BR |  | 2N7002 | CJ(江苏长电/长晶) | C8545 | LCSC
30 | 1 | ALS-PT19-315C/L177/TR8 | Q3 | SENSORS-SMD_ALS-PT19 |  | ALS-PT19-315C/L177/TR8 | EVERLIGHT(亿光) | C146233 | LCSC
31 | 2 | 5.1kΩ | R1,R2 | R0603 | 5.1kΩ | 0603WAF5101T5E | UNI-ROYAL(厚声) | C23186 | LCSC
32 | 24 | 10kΩ | R3,R4,R7,R8,R9,R15,R16,R32,R46,R47,R61,R62,R63,R64,R65,R66,R67,R68,R69,R70,R71,R72,R73,R74 | R0603 | 10kΩ | 0603WAF1002T5E | UNI-ROYAL(厚声) | C25804 | LCSC
33 | 1 | 18kΩ | R5 | R0603 | 18kΩ | 0603WAF1802T5E | UNI-ROYAL(厚声) | C25810 | LCSC
34 | 3 | 1kΩ | R6,R21,R56 | R0603 | 1kΩ | 0603WAF1001T5E | UNI-ROYAL(厚声) | C21190 | LCSC
35 | 1 | 267kΩ | R10 | R0603 | 267kΩ | 0603WAF2673T5E | UNI-ROYAL(厚声) | C22963 | LCSC
36 | 13 | 100kΩ | R11,R12,R13,R14,R17,R33,R34,R35,R36,R37,R38,R39,R45 | R0603 | 100kΩ | 0603WAF1003T5E | UNI-ROYAL(厚声) | C25803 | LCSC
37 | 2 | 33Ω | R18,R19 | R0603 | 33Ω | 0603WAF330JT5E | UNI-ROYAL(厚声) | C23140 | LCSC
38 | 1 | 4.02kΩ | R20 | R0603 | 4.02kΩ | RMC06034.02K1%N | Tyohm(幸亚电阻) | C269496 | LCSC
39 | 7 | 100Ω | R24,R25,R26,R27,R28,R29,R54 | R0603 | 100Ω | 0603WAF1000T5E | UNI-ROYAL(厚声) | C22775 | LCSC
40 | 2 | 2.2kΩ | R30,R31 | R0603 | 2.2kΩ | 0603WAF2201T5E | UNI-ROYAL(厚声) | C4190 | LCSC
41 | 11 | 51kΩ | R40,R41,R42,R43,R44,R48,R49,R50,R51,R52,R53 | R0603 | 51kΩ | 0603WAF5102T5E | UNI-ROYAL(厚声) | C23196 | LCSC
42 | 1 | 1.33Ω | R55 | R0805 | 1.33Ω | RTT051R33FTP | RALEC(旺诠) | C158243 | LCSC
43 | 3 | 22Ω | R57,R58,R59 | R0603 | 22Ω | 0603WAF220JT5E | UNI-ROYAL(厚声) | C23345 | LCSC
44 | 1 | 47kΩ | R60 | R0603 | 47kΩ | 0603WAF4702T5E | UNI-ROYAL(厚声) | C25819 | LCSC
45 | 2 | 0Ω | R75,R76 | R0603 | 0Ω | 0603WAF0000T5E | UNI-ROYAL(厚声) | C21189 | LCSC
46 | 1 | NCP18XH103F03RB | RT1 | R0603 |  | NCP18XH103F03RB | muRata(村田) | C13564 | LCSC
47 | 2 | TS-1187A-B-A-B | SW1,SW2 | SW-SMD_4P-L5.1-W5.1-P3.70-LS6.5-TL_H1.5 |  | TS-1187A-B-A-B | XKB Connection(中国星坤) | C318884 | LCSC
48 | 1 | SS13D07VG4 | SW3 | SW-TH_SS13D07VG4 |  | SS13D07VG4 | SHOU HAN(首韩) | C2681578 | LCSC
49 | 18 | 5017 | TP1,TP2,TP3,TP4,TP5,TP6,TP7,TP8,TP9,TP10,TP11,TP12,TP13,TP14,TP15,TP16,TP17,TP18 | TEST-SMD_L2.7-W1.0 |  | 5017 | Keystone | C238130 | LCSC
50 | 1 | ESP32-P4NRW32 | U1 | QFN-104_L10.0-W10.0-P0.35-TL-EP7.5 |  | ESP32-P4NRW32 | ESPRESSIF(乐鑫) | C22387510 | LCSC
51 | 1 | BQ25185DLHR | U2 | WSON-10_L2.2-W2.0-P0.40-BL-EP_TI_DLH0010A |  | BQ25185DLHR | TI(德州仪器) | C19725033 | LCSC
52 | 1 | TPS62840DLCR | U3 | VSON-8_L2.0-W1.5-P0.50-BL |  | TPS62840DLCR | TI(德州仪器) | C2071859 | LCSC
53 | 3 | TPS22917DBVR | U4,U5,U10 | SOT-23-6_L2.9-W1.6-P0.95-LS2.8-BR |  | TPS22917DBVR | TI(德州仪器) | C2681320 | LCSC
54 | 1 | TPS63021DSJR | U6 | VSON-14_L4.0-W3.0-P0.50-BL-EP_TI_DSJ |  | TPS63021DSJR | TI(德州仪器) | C202140 | LCSC
55 | 1 | TLV62569DBVR | U7 | SOT-23-5_L3.0-W1.7-P0.95-LS2.8-BR |  | TLV62569DBVR | TI(德州仪器) | C141836 | LCSC
56 | 1 | W25Q128JVSIQ | U8 | SOIC-8_L5.3-W5.3-P1.27-LS8.0-BL |  | W25Q128JVSIQ | Winbond(华邦) | C97521 | LCSC
57 | 1 | DRV8837DSGR | U9 | WSON-8_L2.0-W2.0-P0.50-TL-EP |  | DRV8837DSGR | TI(德州仪器) | C39159 | LCSC
58 | 1 | 2.4GHz | U11 | WIFIM-SMD_61P-L16.6-W13.2-P0.80-ESP32-C6-MINI-1-N4 | 2.4GHz | ESP32-C6-MINI-1-N4 | ESPRESSIF(乐鑫) | C5736265 | LCSC
59 | 1 | TPS61165DBVR | U12 | SOT-23-6_L2.9-W1.6-P0.95-LS2.8-BR | - | TPS61165DBVR | TI(德州仪器) | C58756 | LCSC
60 | 1 | PYD 1598 / 7655 | U13 | TO-5-4_BD9.2-P2.54_PYD-1598-7655 |  | PYD 1598 / 7655 | Excelitas(埃赛力达) | C3678555 | LCSC
61 | 1 | FGH100MABMD | U14 | COMM-SMD_FGH100MAAMD |  | FGH100MABMD | Quectel(移远) | C23509203 | LCSC
62 | 1 | 32.768kHz | Y1 | FC-135R_L3.2-W1.5 | 32.768kHz | Q13FC13500004 | EPSON(爱普生) | C32346 | LCSC
63 | 1 | 40MHz | Y2 | CRYSTAL-SMD_4P-L3.2-W2.5-BL | 40MHz | S322540M15PF10PPM | SOSET(索斯特) | C7473041 | LCSC

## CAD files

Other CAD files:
board/build/2026-09-09/board.step
board/build/2026-09-09/board.dxf

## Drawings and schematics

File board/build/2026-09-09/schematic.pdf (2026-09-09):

GPIO24 52 GPIO25 53 NC 54 GPIO26 55 GPIO27 56 GPIO28 57 GPIO29 58 VDDPST 59 GPIO30 60 GPIO31 61 VDDPST_4 62 GPIO32 63 GPIO33 64 GPIO34 65 GPIO35 66 VDDPST 67 GPIO36 68 GPIO37 69 GPIO38 70 VFB/VO1 71 VFB/VO2 72 VFB/VO3 73 VFB/VO4 74 VDDPST_LDO 75 VDD_HP_2 76 VDDPST_DCDC 77 FB_DCDC 78 EN_DCDC 79 GPIO39 80 GPIO40 81 GPIO41 82 GPIO42 83 GPIO43 84 VDDPST_5 85 GPIO44 86 GPIO45 87 GPIO46 88 GPIO47 89 GPIO48 90 VDD_HP_3 91 GPIO49 92 GPIO50 93 GPIO51 94 GPIO52 95 VDDPST_6 96 GPIO53 97 GPIO54 98 XTAL_N 99 XTAL_P 100 VDDA 101 VBAT 102 CHIP_PU 103 GPIO0 104 GND 105

R15

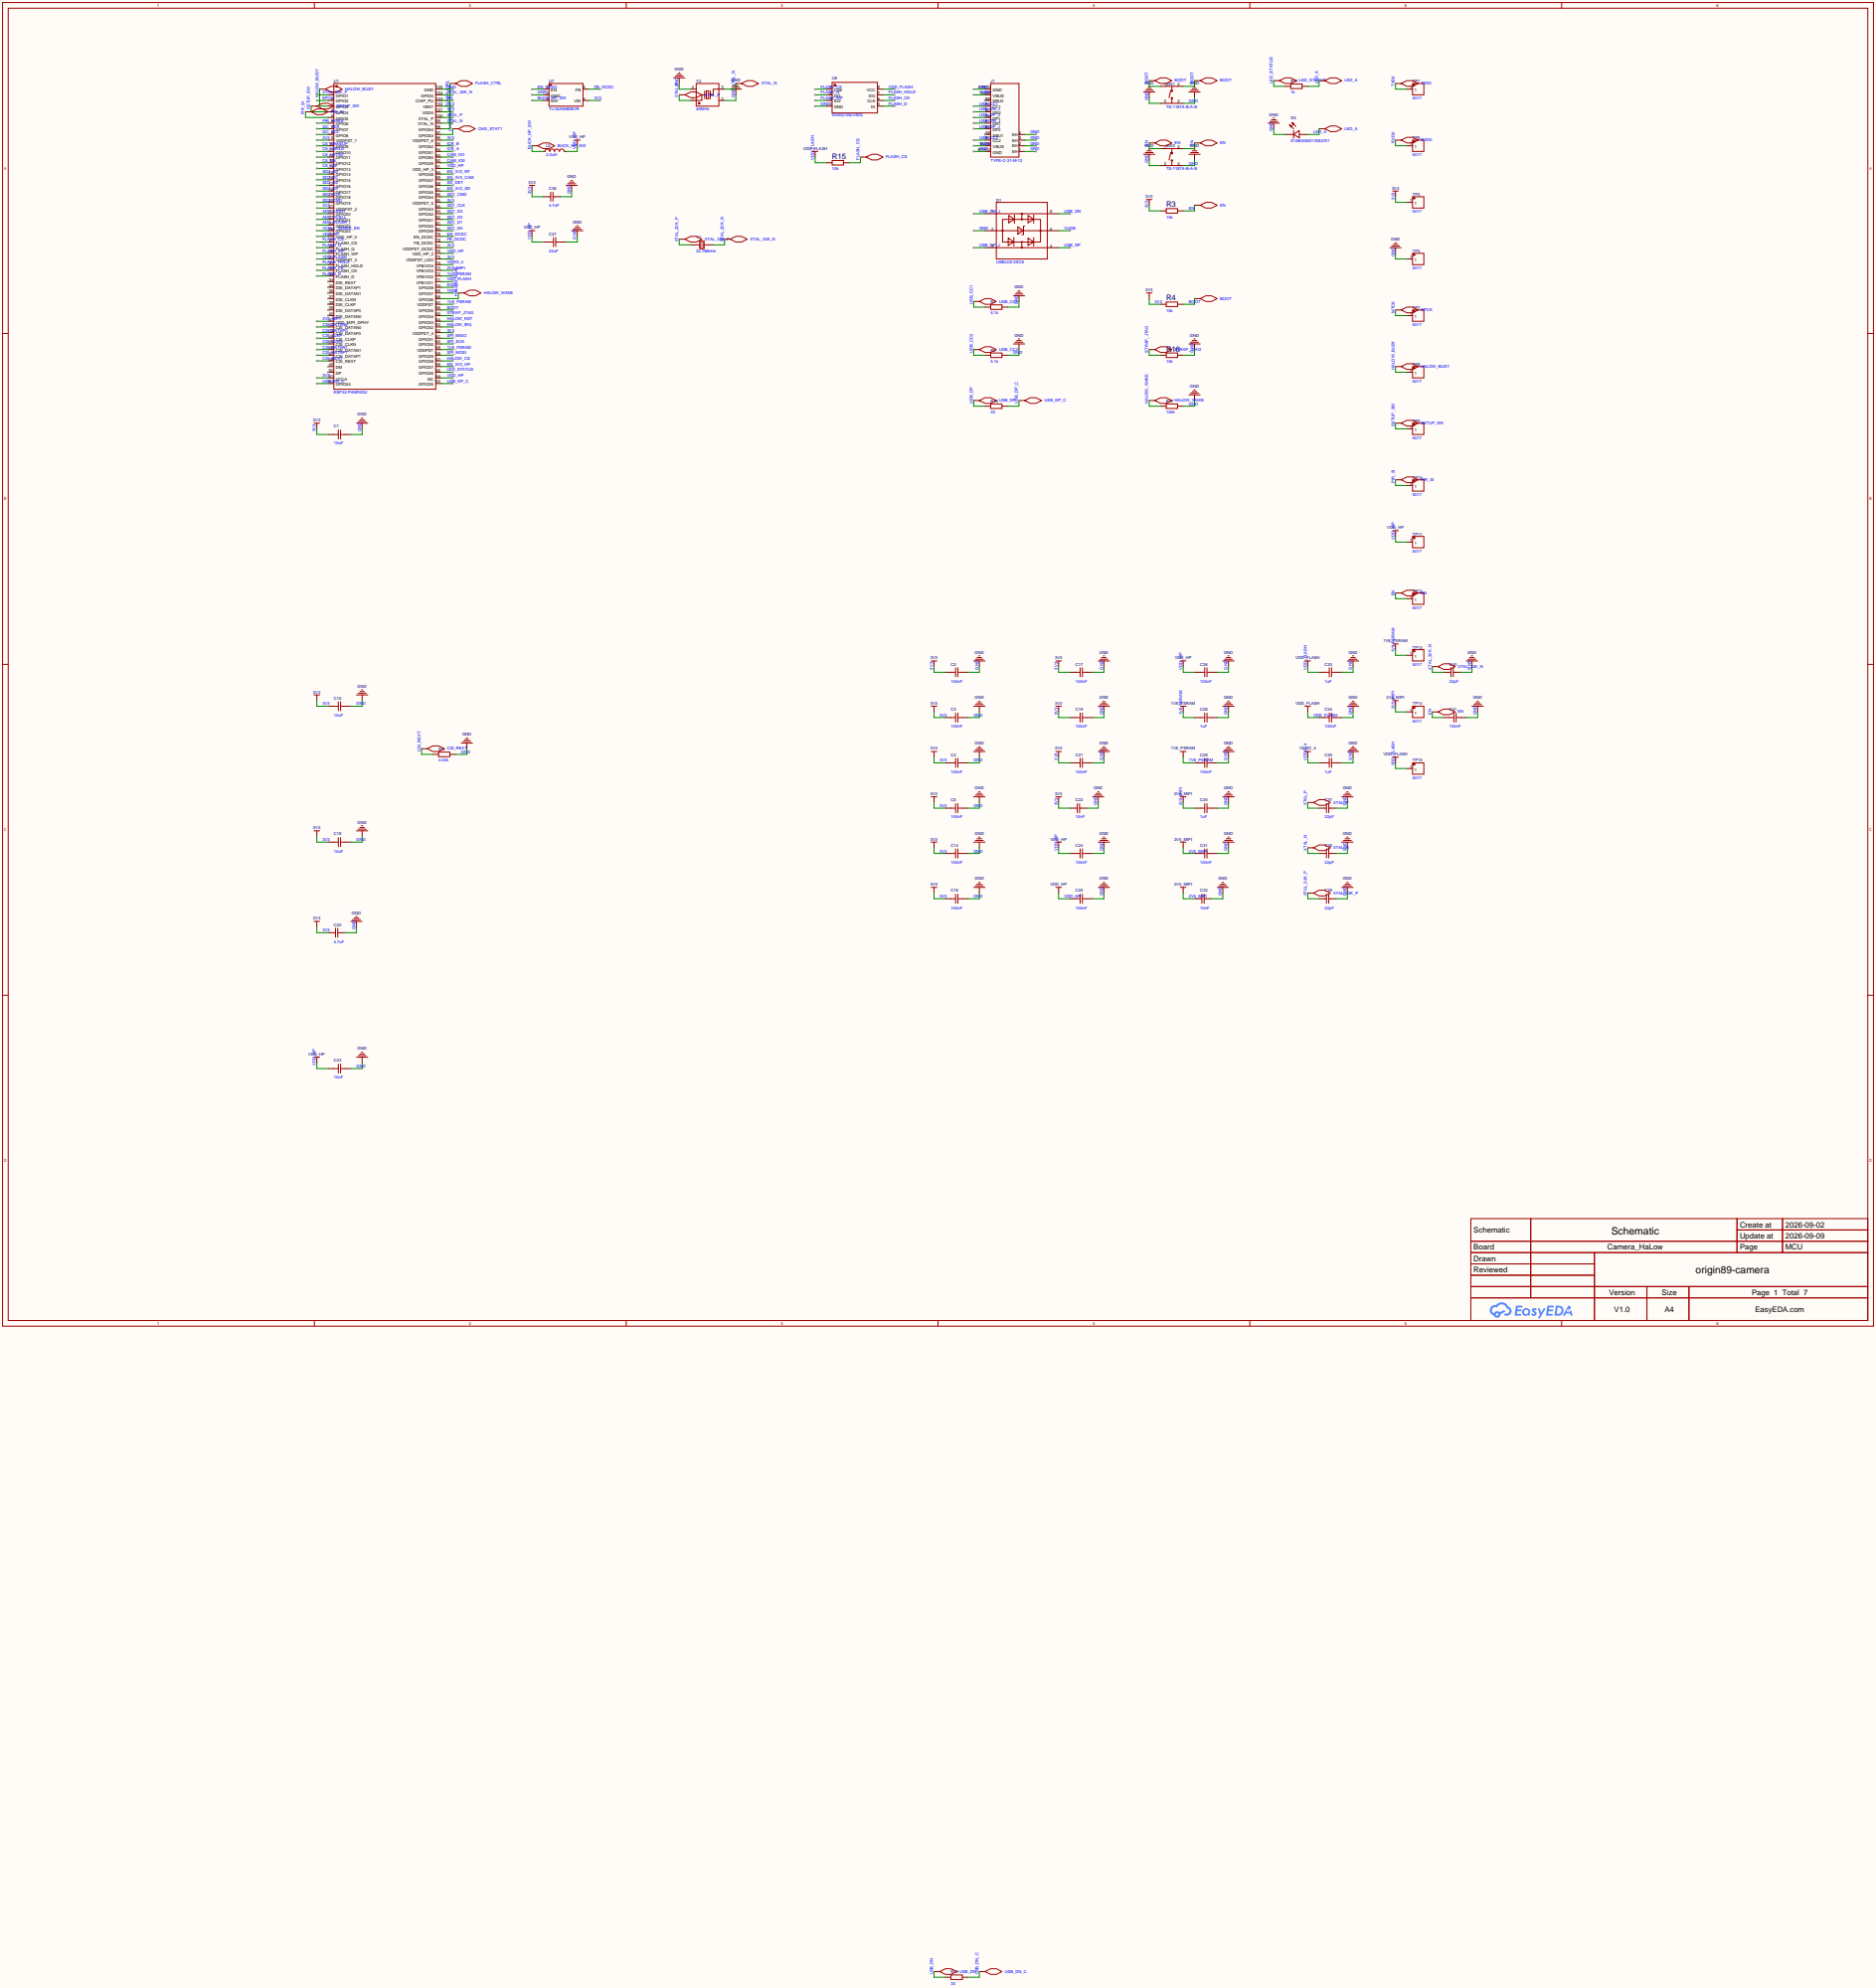
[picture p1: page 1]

Schematic | Schematic | Create at | 2026-09-02

Update at | 2026-09-09

Board | Camera_HaLow | Page | MCU
Drawn | | origin89-camera
Reviewed

Version | Size | Page 1 Total 7
V1.0 | A4 | EasyEDA.com

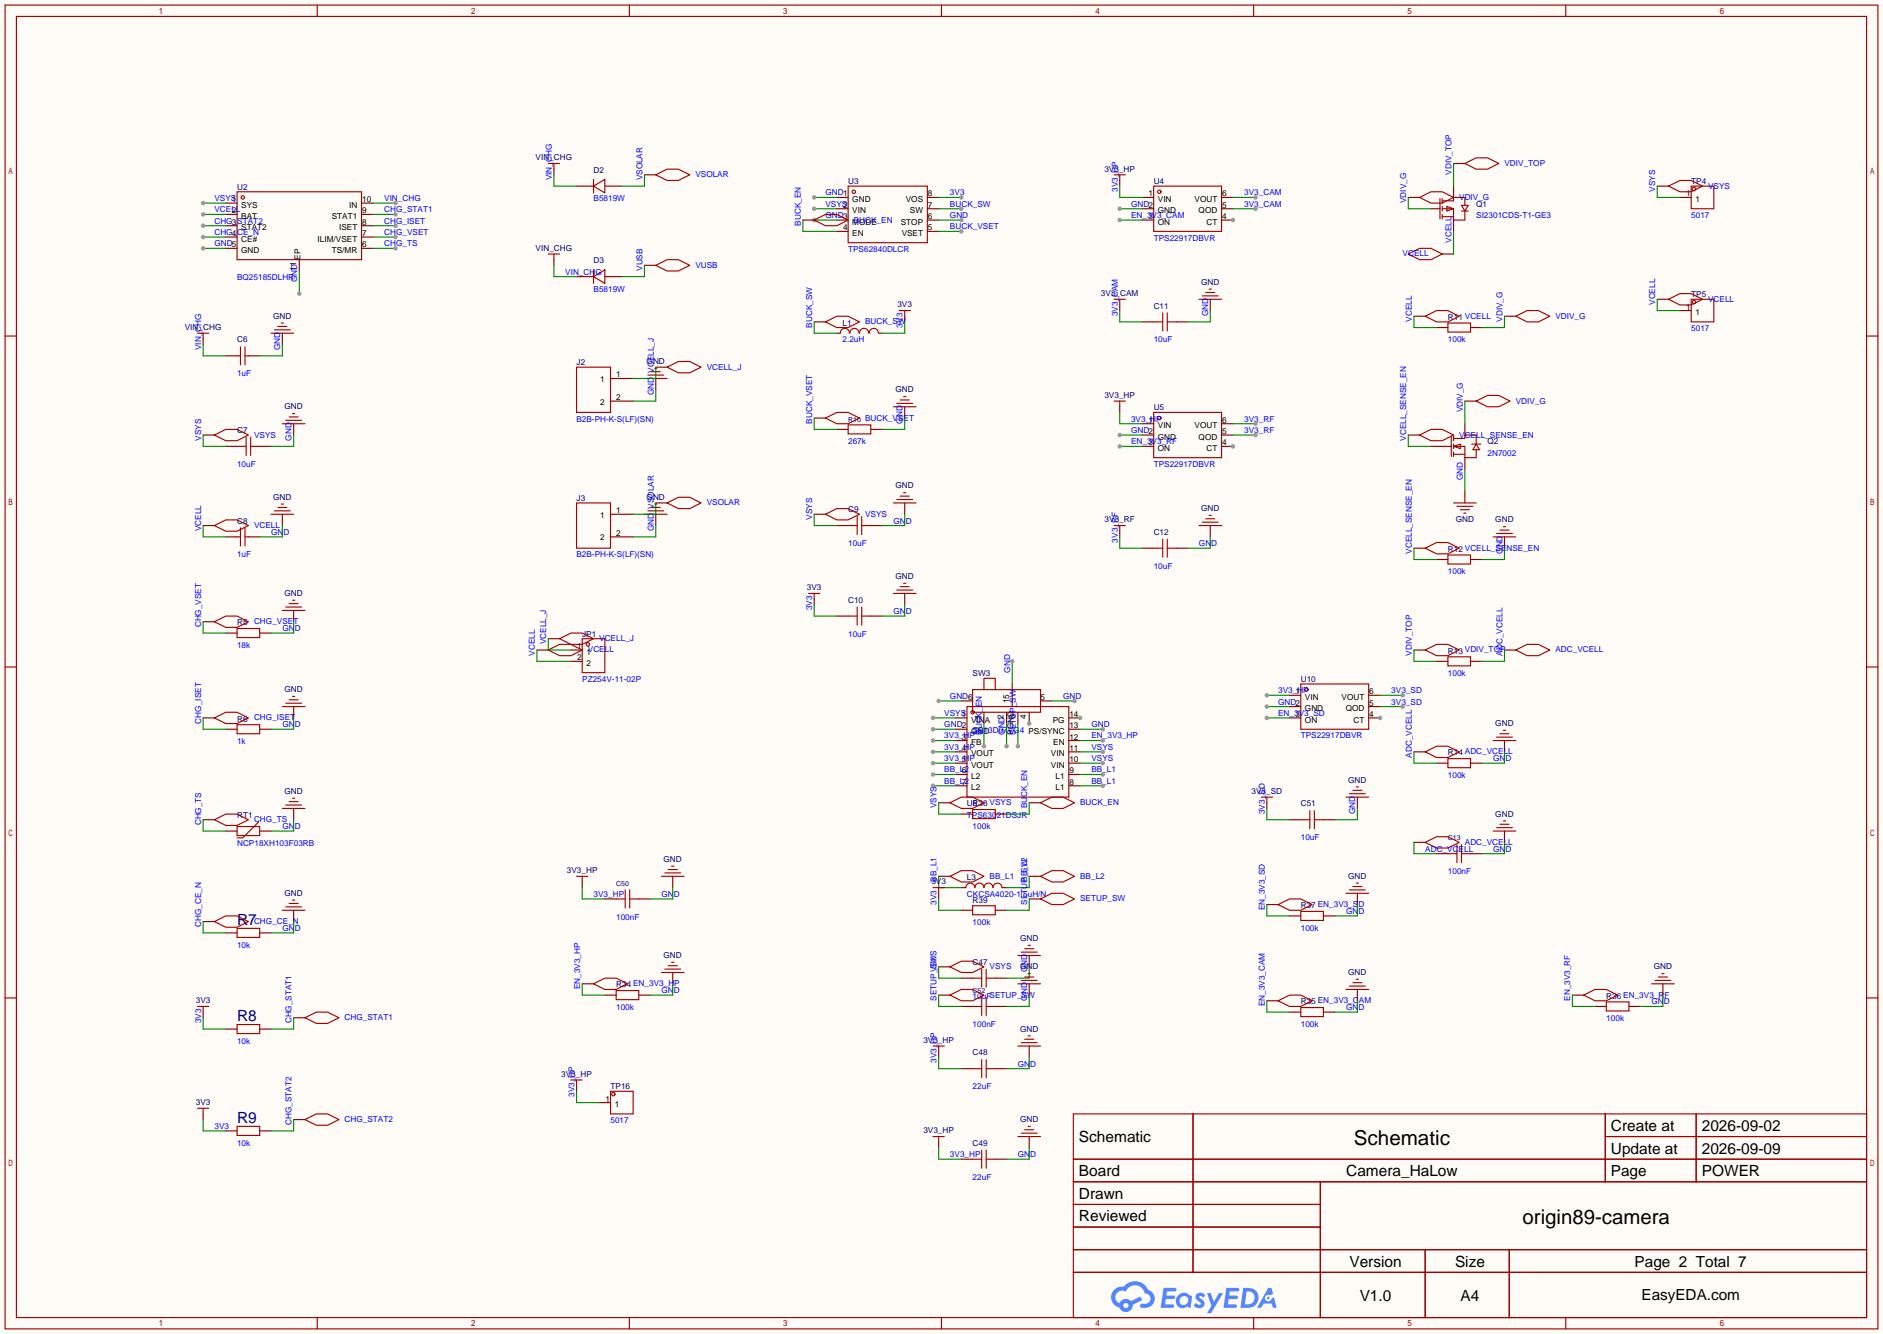
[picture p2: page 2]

PGND 15
VIN 10 VIN 11 EN 12 PS/SYNC 13 PG 14

Schematic | Schematic | Create at | 2026-09-02

Update at | 2026-09-09

Board | Camera_HaLow | Page | POWER
Drawn | | origin89-camera
Reviewed

Version | Size | Page 2 Total 7
V1.0 | A4 | EasyEDA.com

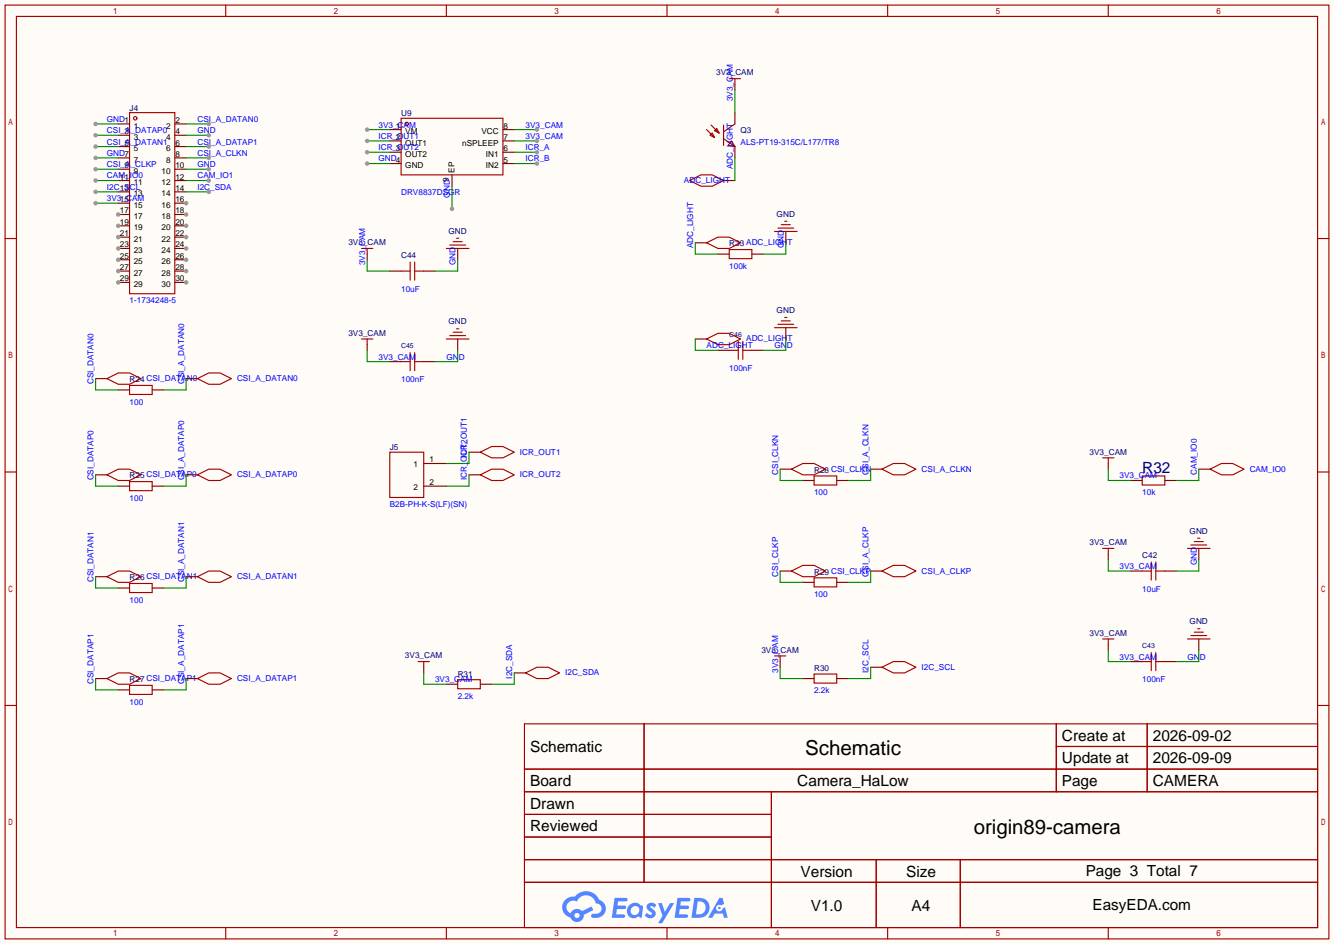
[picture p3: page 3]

Schematic | Schematic | Create at | 2026-09-02

Update at | 2026-09-09

Board | Camera_HaLow | Page | CAMERA
Drawn | | origin89-camera
Reviewed

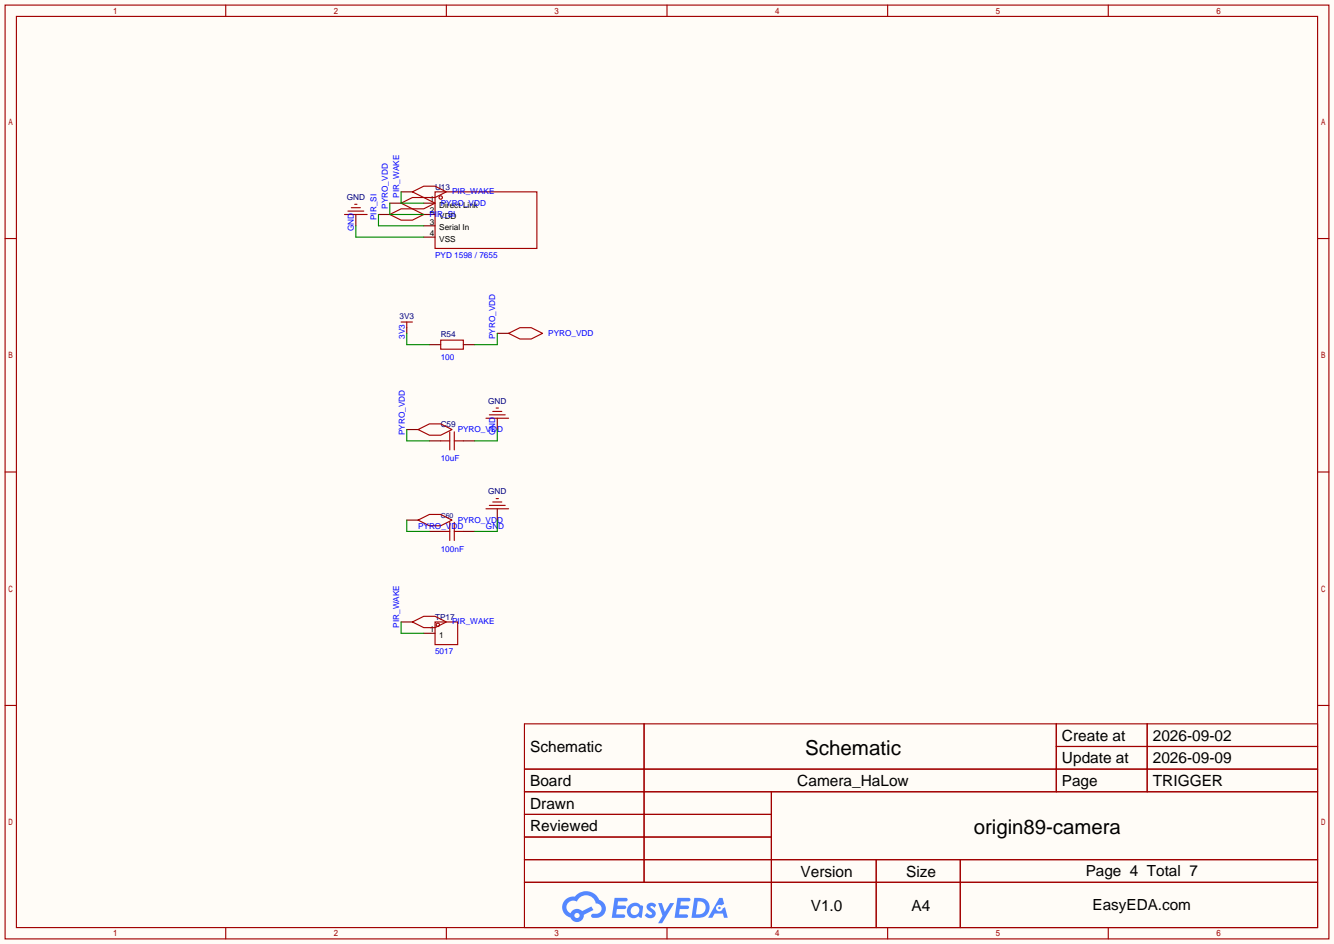
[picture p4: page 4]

Schematic | Schematic | Create at | 2026-09-02

Update at | 2026-09-09

Board | Camera_HaLow | Page | TRIGGER
Drawn | | origin89-camera
Reviewed

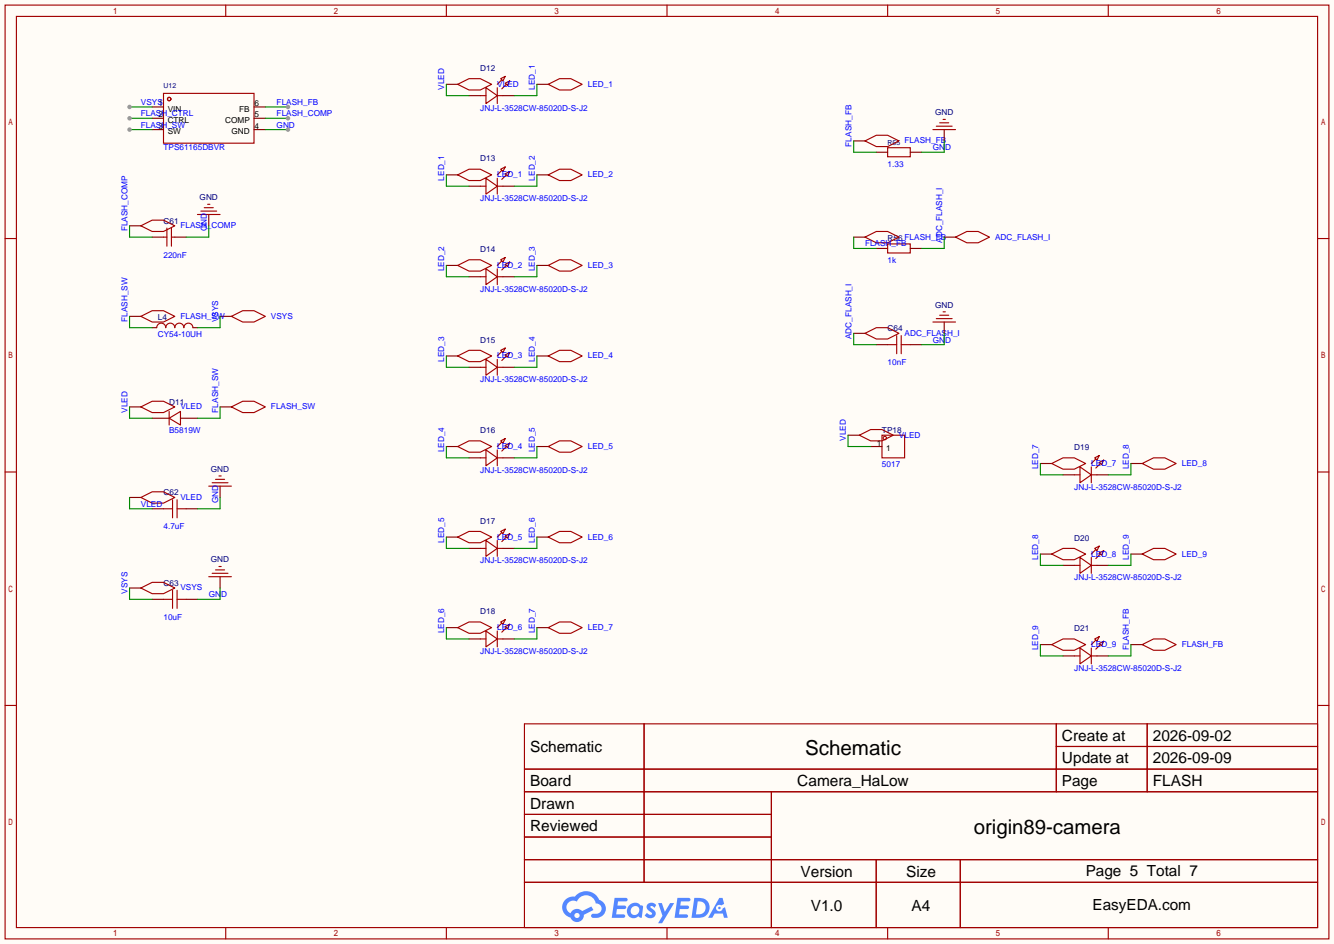
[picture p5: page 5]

Schematic | Schematic | Create at | 2026-09-02

Update at | 2026-09-09

Board | Camera_HaLow | Page | FLASH
Drawn | | origin89-camera
Reviewed

IO21 27 IO22 28 IO23 29 RXD0 30 TXD0 31 NC 32 NC 33 NC 34 NC 35 GND 36 GND 37 GND 38 GND 39 GND 40 GND 41 GND 42 GND 43 GND 44 GND 45 GND 46 GND 47 GND 48 GND 49 GND 50 GND 51 GND 52 GND 53

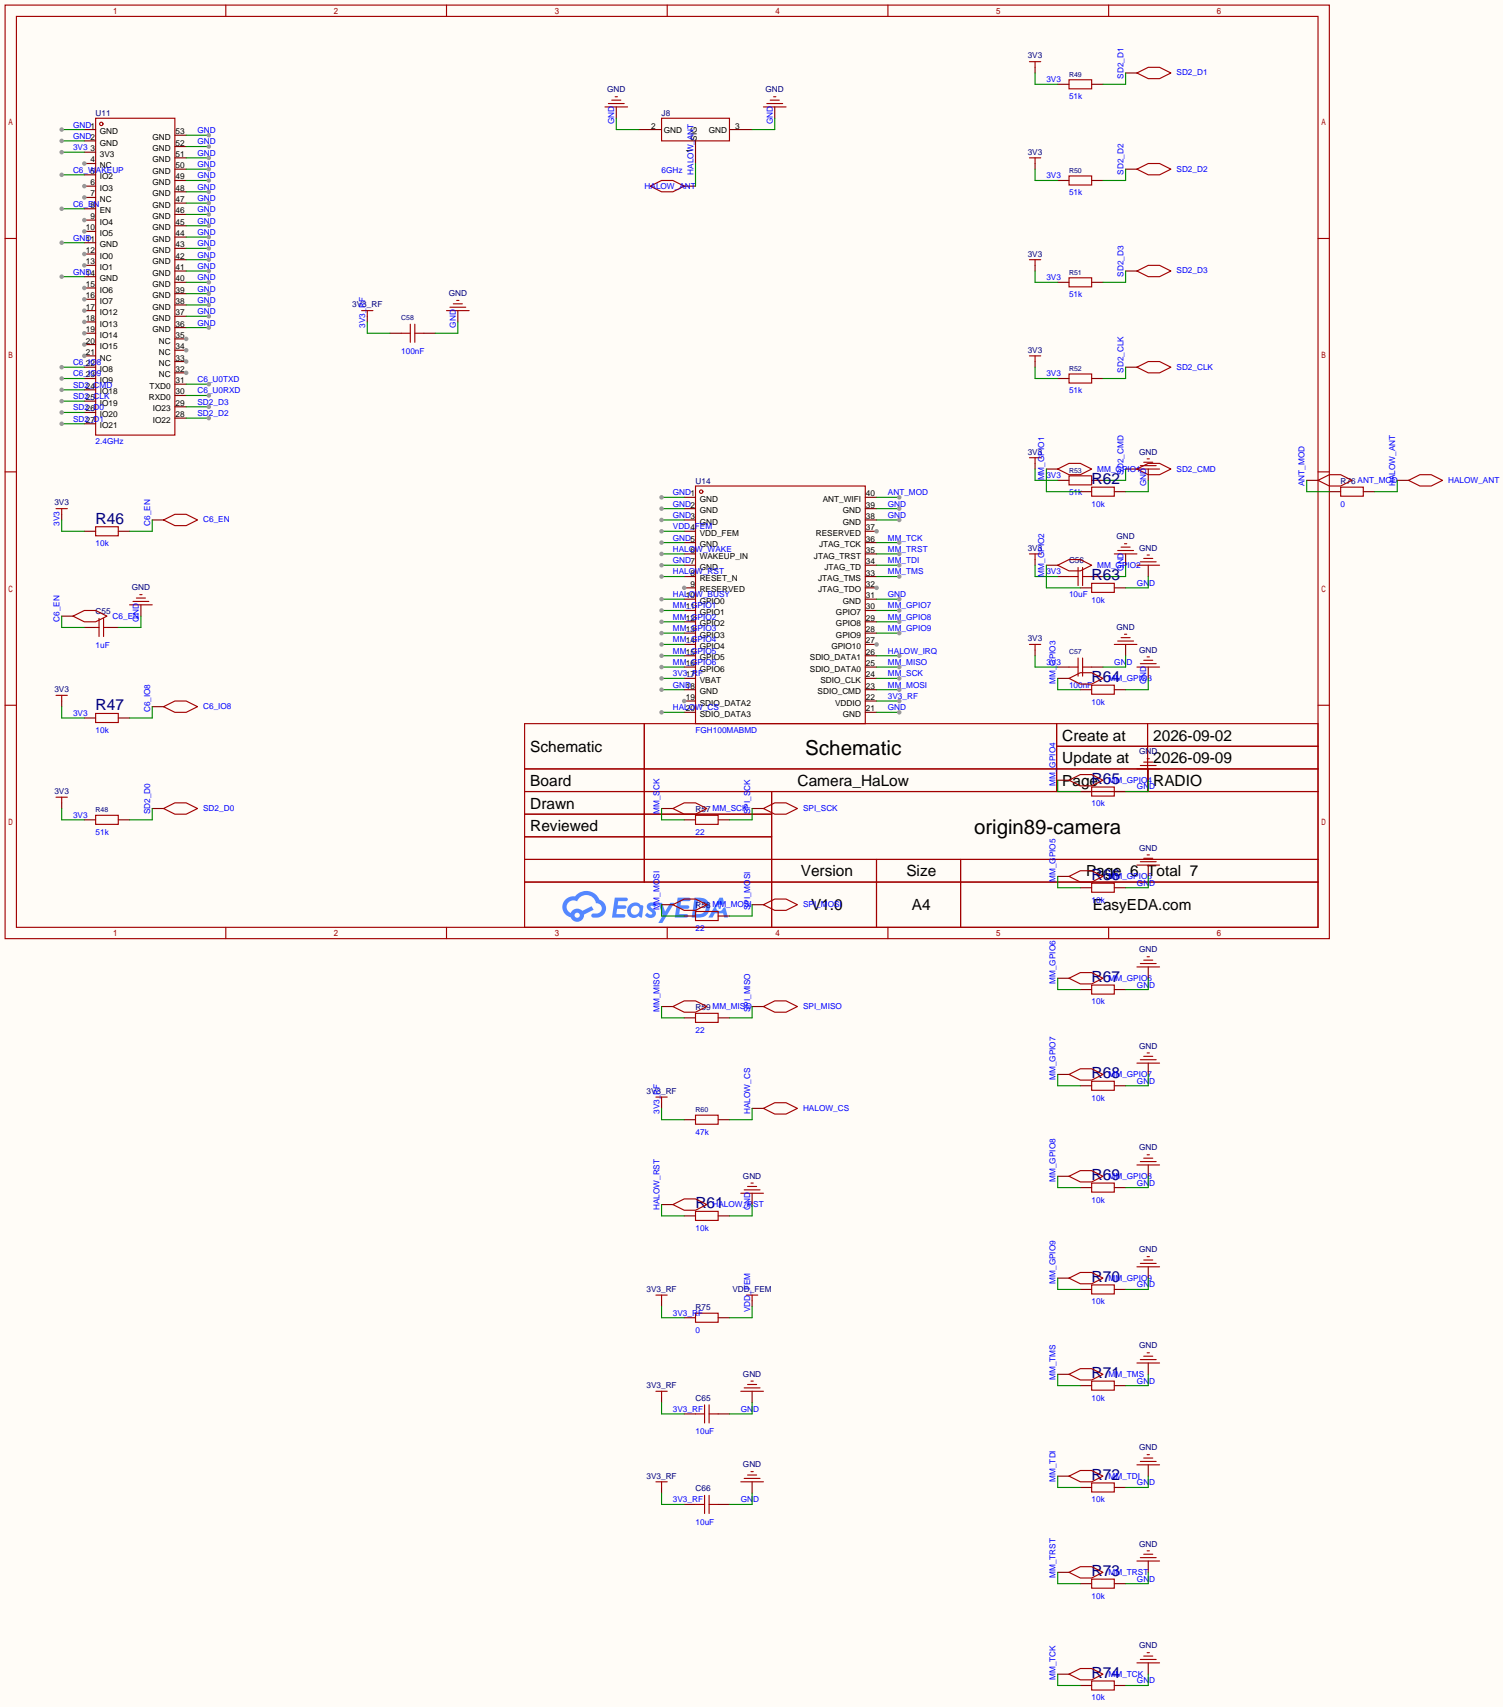
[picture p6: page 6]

Schematic | FGH100MABMD Schematic | Create at | 2026-09-02

GND Update at | 2026-09-09
R65

Drawn | | 10k origin89-camera GND
Reviewed | 22

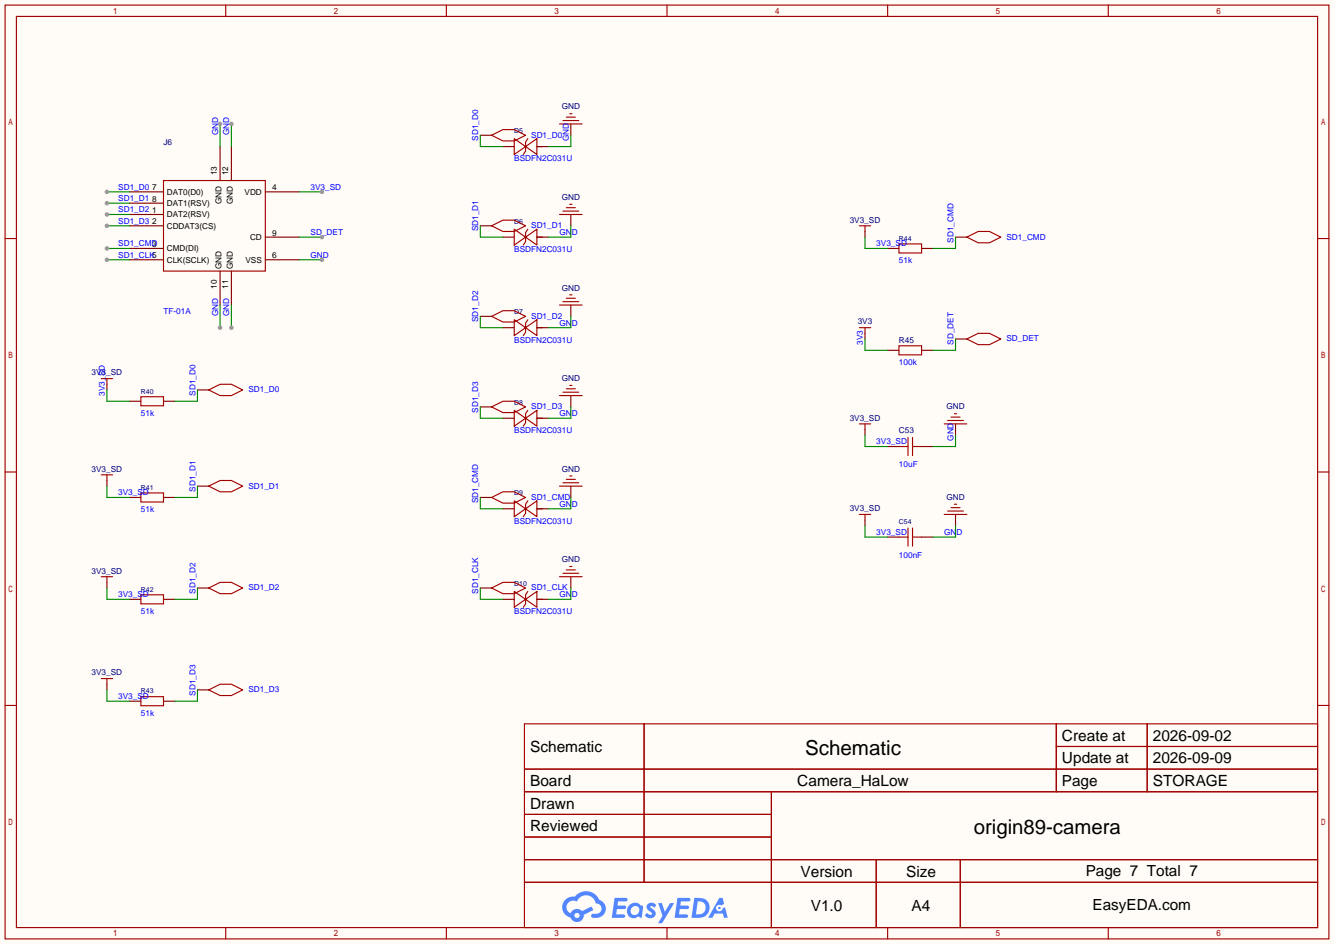
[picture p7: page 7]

Schematic | Schematic | Create at | 2026-09-02

Update at | 2026-09-09

Board | Camera_HaLow | Page | STORAGE
Drawn | | origin89-camera
Reviewed

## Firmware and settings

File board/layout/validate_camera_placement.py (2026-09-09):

#!/usr/bin/env python3
"""Check the camera board's placement against CAMERA-LAYOUT.md.

Usage: validate_camera_placement.py [<router run directory>]

Reads real pad geometry (see padgeom.py) from the newest router run, or
the one given, and measures every C-nn rule that a placement can satisfy
or break: bands, axis, crystals, converters, the P4's capacitors, and
overlaps between any two parts. Exit 0 when everything passes, 1 on any
FAIL. What this cannot see (copper, pours, the antenna void, the
impedance report) is listed under Acceptance in the document.

Distances are pad to pad on the named net where the rule is about a
connection, centre to centre where it is about a field (an inductor, the
pyro), and the document says which.
"""
import itertools
import sys

from padgeom import Board, overlaps

EPS = 1e-3  # EasyEDA's 0.1 mm grid comes back as 6.2000000004; a check is not a float comparison
# Parts that cast a shadow on the pyro window. L2 is not among them: the
# core buck is off whenever the pyro is the only thing awake (the P4 drives
# EN_DCDC low in deep sleep), and it is 1.5 mm high.
TALL = ["U11", "U14", "L1", "L3", "L4", "J6", "J1", "SW3", "J4", "U13"]
DOOR = ("J6", "J1", "SW3")
SUPPLY_NETS = ("3V3", "VDD_HP", "1V8_PSRAM", "2V5_MIPI", "VDD_FLASH", "VDDO_4")


class Report:
    def __init__(self):
        self.failures = []

    def check(self, req, label, value, limit, kind="<="):
        ok = value <= limit + EPS if kind == "<=" else value >= limit - EPS
        print(f"  {'ok  ' if ok else 'FAIL'} {req:5} {label}: {value:.2f} mm ({'max' if kind == '<=' else 'min'} {limit})")
        if not ok:
            self.failures.append(f"{req} {label}")

    def expect(self, req, label, ok, detail=""):
        print(f"  {'ok  ' if ok else 'FAIL'} {req:5} {label}{(': ' + detail) if detail else ''}")
        if not ok:
            self.failures.append(f"{req} {label}")


def mechanical(b, r):
    xs = [p[0] for p in b.outline]
    ys = [p[1] for p in b.outline]
    r.check("C-01", "outline width off 80", abs(max(xs) - min(xs) - 80.0), 0.05)
    r.check("C-01", "outline height off 100", abs(max(ys) - min(ys) - 100.0), 0.05)
    r.check("C-01", "outline centred (max offset)", max(abs(max(xs) + min(xs)), abs(max(ys) + min(ys))) / 2, 0.1)
    holes = {(round(h.x), round(h.y)) for h in b.holes()}
    r.expect("C-02", "four holes at (±36, ±46)", holes == {(36, 46), (-36, 46), (36, -46), (-36, -46)}, str(sorted(holes)))
    bottom = [d for d in b.designators() if b.layer(d) != 1]
    r.expect("C-05", "every part on the top side", not bottom, ", ".join(bottom))


def bands(b, r):
    door = set(DOOR)
    below = {d for d in b.designators() if b.centre(d)[1] < -38}
    r.expect("C-06", "door band holds J6, J1, SW3", door <= below, ", ".join(sorted(door - below)) + " missing")
    # a door part's own satellites (CC resistors and ESD at the USB, the
    # card's pull-ups, TVS and supply capacitor) belong at the connector:
    # anything sharing a net other than ground or the always-on rail with a
    # door part may sit in the band, nothing else may
    door_nets = {p.net for d in door for p in b.pads_of(d) if p.net not in ("GND", "3V3", "")}
    strangers = {d for d in below - door if not any(p.net in door_nets for p in b.pads_of(d))}
    r.expect("C-06", "nothing but the door parts and their satellites in the band", not strangers, ", ".join(sorted(strangers)))
    order = sorted(door, key=lambda d: b.centre(d)[0])
    r.expect("C-06", "door order J6, J1, SW3 left to right", order == ["J6", "J1", "SW3"], " ".join(order))
    leds = [f"D{n}" for n in range(12, 22)]
    above = {d for d in b.designators() if b.centre(d)[1] > 40}
    r.expect("C-07", "LED band holds D12-D21", set(leds) <= above, ", ".join(sorted(set(leds) - above)) + " missing")
    r.expect("C-07", "nothing else in the LED band", above <= set(leds), ", ".join(sorted(above - set(leds))))
    ys = [b.centre(d)[1] for d in leds]
    r.check("C-07", "LED row straight (y spread)", max(ys) - min(ys), 0.3)
    xs = sorted(b.centre(d)[0] for d in leds)
    pitches = [xs[i + 1] - xs[i] for i in range(len(xs) - 1)]
    r.check("C-07", "LED pitch (min)", min(pitches), 5.8, ">=")
    r.check("C-07", "LED pitch (max)", max(pitches), 6.2)


def axis(b, r):
    jx, jy = b.centre("J4")
    r.check("C-08", "J4 on the centreline |x|", abs(jx), 0.3)
    r.check("C-08", "J4 8 mm above centre |y-8|", abs(jy - 8), 0.5)
    for pin in range(42, 48):
        p = b.pad("U1", pin)
        # the series resistor: one pad on the P4's net, the other on J4's
        for res in ("R24", "R25", "R26", "R27", "R28", "R29"):
            pads = b.pads_of(res)
            if any(q.net == p.net for q in pads):
                near = next(q for q in pads if q.net == p.net)
                far = next(q for q in pads if q.net != p.net)
                jpad = next(q for q in b.pads_of("J4") if q.net == far.net)
                r.check("C-08", f"CSI pin {pin} -> {res} -> J4 path", p.distance(near) + far.distance(jpad), 15.0)
                break
        else:
            r.expect("C-08", f"CSI pin {pin} has a series resistor", False)
    px, py = b.centre("U13")
    r.check("C-09", "pyro on the centreline |x|", abs(px), 1.0)
    r.check("C-09", "pyro about 28 mm below centre |y+28|", abs(py + 28), 4.0)
    r.check("C-09", "light sensor Q3 beside the pyro", b.centre_distance("U13", "Q3"), 10.0)
    for d in TALL:
        if d != "U13":
            r.check("C-09", f"{d} clear of the pyro window", b.centre_distance("U13", d), 8.0, ">=")


def edges(b, r):
    x, y = b.centre("J8")
    r.check("C-10", "U.FL on the left edge (x)", x, -30, "<=")
    r.check("C-10", "U.FL upper half |y-25|", abs(y - 25), 10.0)
    a = b.pad("U14", 40)
    rf_in = next(q for q in b.pads_of("R76") if q.net == a.net)
    rf_out = next(q for q in b.pads_of("R76") if q.net != a.net)
    r.check("C-10", "RF run U14.40 -> R76 -> J8", a.distance(rf_in) + rf_out.distance(b.pad("J8", 1)), 15.0)
    x, y = b.centre("U11")
    r.check("C-11", "C6 module at the right edge (x)", x, 20, ">=")
    r.check("C-11", "C6 module in the upper half (y)", y, 0, ">=")
    for d in ("J2", "J3"):
        x, y = b.centre(d)
        r.check("C-12", f"{d} on the left edge (x)", x, -30, "<=")
        r.check("C-12", f"{d} in the lower half (y)", y, 0, "<=")
    r.check("C-12", "JP1 beside J2", b.centre_distance("JP1", "J2"), 10.0)
    for n in range(1, 19):
        x, y = b.centre(f"TP{n}")
        r.expect("C-13", f"TP{n} in the right lower quadrant", x >= 20 and y <= 0, f"({x:.1f}, {y:.1f})")
    for d in ("SW1", "SW2"):
        r.check("C-13", f"{d} off the door edge (y)", b.centre(d)[1], -38, ">=")


def placement(b, r):
    # the 40 MHz crystal hangs under the ring; its far pad is allowed 6.5 mm (C-31 says why)
    for xtal, pins in (("Y2", (99, 100)), ("Y1", (1, 104))):
        for pin in pins:
            p = b.pad("U1", pin)
            d = min(q.distance(p) for q in b.pads_of(xtal) if q.net == p.net)
            r.check("C-31", f"{xtal} to pin {pin} ({p.net})", d, 6.5 if (xtal, pin) == ("Y2", 99) else 5.0)
        for coil in ("L1", "L3", "L4"):
            r.check("C-31", f"{xtal} clear of {coil}", b.centre_distance(xtal, coil), 10.0, ">=")
        r.check("C-31", f"{xtal} clear of L2", b.centre_distance(xtal, "L2"), 5.0, ">=")
    for d in ("U6", "L3"):
        for v in ("Y1", "Y2", "U13"):
            r.check("C-33", f"{d} clear of {v}", b.centre_distance(d, v), 10.0, ">=")
    for d in ("U3", "L1"):
        r.check("C-34", f"{d} clear of the pyro", b.centre_distance(d, "U13"), 10.0, ">=")
        r.check("C-34", f"{d} clear of Q3", b.centre_distance(d, "Q3"), 5.0, ">=")
    caps = [d for d in b.designators() if d.startswith("C")]
    for p in b.pads_of("U1"):
        if p.net not in SUPPLY_NETS:
            continue
        best = None
        for c in caps:
            for q in b.pads_of(c):
                if q.net == p.net:
                    dd = q.distance(p)
                    if best is None or dd < best[0]:
                        best = (dd, c)
        r.check("C-35", f"pin {p.number} {p.net} capacitor ({best[1]})", best[0], 3.0)
    r.check("C-38", "R20 to pin 48 (CSI_REXT)", min(q.distance(b.pad("U1", 48)) for q in b.pads_of("R20") if q.net == "CSI_REXT"), 3.0)
    for res in ("R57", "R58", "R59"):
        r.check("C-39", f"{res} at the HaLow module", b.pad_distance(res, "U14"), 5.0)
    flash = min(b.pad("U1", n).distance(q) for n in range(27, 34) for q in b.pads_of("U8") if q.net == b.pad("U1", n).net)
    r.check("C-40", "flash U8 to the P4's QSPI pins", flash, 10.0)
    r.check("C-40", "R15 at U8", b.pad_distance("R15", "U8", "FLASH_CS"), 5.0)
    for d in ("U12", "D11", "C62"):
        y = b.centre(d)[1]
        r.expect("C-41", f"{d} just below the LED band", 25 <= y <= 40, f"y = {y:.1f}")
    r.check("C-41", "L4 at its driver U12 (switch-node loop)", b.pad_distance("L4", "U12", "FLASH_SW"), 8.0)
    r.check("C-41", "C62 at D11", b.pad_distance("C62", "D11", "VLED"), 4.0)
    for d in ("U9", "J5"):
        r.check("C-42", f"{d} near the camera connector", b.centre_distance(d, "J4"), 15.0)


def collisions(b, r):
    boxes = {d: b.box(d) for d in b.designators()}
    hits = [(a, c) for a, c in itertools.combinations(sorted(boxes), 2) if overlaps(boxes[a], boxes[c])]
    r.expect("C-05", "no two parts overlap (pad extents + 0.25 mm)", not hits, ", ".join(f"{a}/{c}" for a, c in hits[:12]))


def main():
    b = Board(sys.argv[1] if len(sys.argv) > 1 else None)
    print(f"placement from {b.run_dir}")
    r = Report()
    for section in (mechanical, bands, axis, edges, placement, collisions):
        print(f"\n{section.__name__}")
        section(b, r)
    print()
    if r.failures:
        print(f"{len(r.failures)} FAIL:")
        for f in r.failures:
            print("  " + f)
        return 1
    print("all placement checks pass")
    return 0


if __name__ == "__main__":
    sys.exit(main())

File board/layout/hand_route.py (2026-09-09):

#!/usr/bin/env python3
"""Draw one track on the routing layers, around everything already there.

    from hand_route import Copper
    copper = Copper()                       # newest router artifact
    r = copper.route("I2C_SCL", (14.063, -10.69), (12.419, 10.397), goal_layers=("TOP",))
    copper.verify("I2C_SCL", r)             # (gap, offender): exact, not the grid

Usage as a script: hand_route.py <net> x0 y0 x1 y1 [width]

A* over a 0.05 mm grid on Top, Inner2 and Bottom, every other net's pad,
track and via inflated by its own half width plus the clearance plus
ours, the board edge by its own rule; a layer change is allowed on any
cell where a via clears both layers and costs VIA_COST of path. The path
comes back as straight and 45-degree runs per layer plus the vias, and
`verify` measures it against the exact shapes so a corner the grid cut is
caught before the board sees it.

Why: freerouting stops with a handful of connections open and its answer
to "why" is a window that says nothing. A link drawn by eye from a
preview was 0.09 mm from a capacitor once. The artifact has every shape;
drawing against it is the honest way to finish by hand.
"""
import heapq
import json
import math
import os
import sys

from padgeom import Board, Pad

CLEARANCE = 0.127
EDGE = 0.3
STEP = 0.05
BEND = 0.03  # extra cost per direction change: fewer stairs, straighter copper
MARGIN = 4.0  # mm around the two ends that the search may wander into
HOLE_TO_HOLE = 0.254
VIA_COST = 0.8  # a via costs as much as 0.8 mm of track: taken when it saves more than that
LAYERS = ("TOP", "INNER_2", "BOTTOM")  # Inner1 is the plane (C-04); a through via reaches all three

DIRS = [(1, 0, 1.0), (-1, 0, 1.0), (0, 1, 1.0), (0, -1, 1.0),
        (1, 1, math.sqrt(2)), (1, -1, math.sqrt(2)), (-1, 1, math.sqrt(2)), (-1, -1, math.sqrt(2))]


def seg_point(a, b, p):
    vx, vy = b[0] - a[0], b[1] - a[1]
    l2 = vx * vx + vy * vy
    if l2 < 1e-12:
        return math.hypot(p[0] - a[0], p[1] - a[1])
    t = max(0.0, min(1.0, ((p[0] - a[0]) * vx + (p[1] - a[1]) * vy) / l2))
    return math.hypot(p[0] - a[0] - t * vx, p[1] - a[1] - t * vy)


def seg_seg(a, b, c, d):
    """Distance between segments a-b and c-d."""
    def cross(o, p, q):
        return (p[0] - o[0]) * (q[1] - o[1]) - (p[1] - o[1]) * (q[0] - o[0])
    if (cross(a, b, c) * cross(a, b, d) < 0) and (cross(c, d, a) * cross(c, d, b) < 0):
        return 0.0
    return min(seg_point(a, b, c), seg_point(a, b, d), seg_point(c, d, a), seg_point(c, d, b))


def point_in_poly(p, poly):
    inside = False
    for (x0, y0), (x1, y1) in zip(poly, poly[1:] + poly[:1]):
        if (y0 > p[1]) != (y1 > p[1]) and p[0] < x0 + (p[1] - y0) * (x1 - x0) / (y1 - y0):
            inside = not inside
    return inside


def seg_poly(a, b, poly):
    """Distance from segment a-b to a filled polygon; 0 inside it."""
    if point_in_poly(a, poly) or point_in_poly(b, poly):
        return 0.0
    return min(seg_seg(a, b, c, d) for c, d in zip(poly, poly[1:] + poly[:1]))


def seg_rect(a, b, r):
    """Distance from segment a-b to an axis-aligned rectangle (x0, y0, x1, y1)."""
    x0, y0, x1, y1 = r
    if (x0 <= a[0] <= x1 and y0 <= a[1] <= y1) or (x0 <= b[0] <= x1 and y0 <= b[1] <= y1):
        return 0.0
    edges = [((x0, y0), (x1, y0)), ((x1, y0), (x1, y1)), ((x1, y1), (x0, y1)), ((x0, y1), (x0, y0))]
    return min(seg_seg(a, b, c, d) for c, d in edges)


class Copper:
    """Everything on the board that a new track has to keep away from."""

    def __init__(self, run_dir=None):
        self.board = Board(run_dir)
        raw = json.load(open(os.path.join(self.board.run_dir, "copilot-router-input.json")))["board"]
        self.tracks = [(t["net"], t["layer"], t.get("widthMm") or 0.2, [(p["x"], -p["y"]) for p in t["points"]])
                       for g in raw["copper"] for t in raw["copper"][g]["tracks"]]
        self.vias = [(v["net"], v["at"]["x"], -v["at"]["y"], v["diameterMm"]) for g in raw["copper"] for v in raw["copper"][g].get("vias", [])]
        self.pads = [(p.get("net", ""), p["layers"], Pad(p)) for p in raw["pads"]]
        # a prohibited region is copper's obstacle whatever the net: the C6's
        # antenna void (C-11) took three ground stubs that were drawn without it
        self.keepouts = [([(q["x"], -q["y"]) for q in k["polygon"]["outer"]], k.get("layers") or [], k.get("forbid") or {})
                         for k in (raw.get("keepouts") or []) if k.get("polygon", {}).get("outer")]
        xs = [x for x, _ in self.board.outline]
        ys = [y for _, y in self.board.outline]
        self.edge = (min(xs), min(ys), max(xs), max(ys))

    def obstacles(self, layer, net):
        """(kind, shape, keep) for everything not on `net` that touches `layer`,
        or every layer when `layer` is None (a through via meets the inner
        tracks too, and one landed on an Inner2 wire before this said so);
        keep is the distance our centreline must stay from the shape."""
        out = []
        for n, lay, w, pts in self.tracks:
            if n != net and (layer is None or lay == layer):
                for a, b in zip(pts, pts[1:]):
                    out.append(("seg", (a, b), w / 2))
        for n, x, y, d in self.vias:
            if n != net:
                out.append(("circle", (x, y), d / 2))
        for n, layers, pad in self.pads:
            if n != net and (layer is None or layer in layers or len(layers) > 1):
                out.append(("rect", pad.rect(), 0.0))
        for poly, layers, forbid in self.keepouts:
            if forbid.get("tracks", True) and (layer is None or layer in layers):
                out.append(("poly", poly, 0.0))
        return out


    def check(self, net, layer, pts, width=0.127):
        """Smallest gap between the polyline and anything not on its net, with the
        offender. The rule is CLEARANCE: a result below it is a violation, a
        result below zero is an overlap."""
        worst = (float("inf"), None)
        obstacles = self.obstacles(layer, net)
        for a, b in zip(pts, pts[1:]):
            for kind, shape, keep in obstacles:
                d = distance(kind, shape, a, b) - keep - width / 2
                if d < worst[0]:
                    worst = (d, (kind, shape))
            x0, y0, x1, y1 = self.edge
            for p in (a, b):
                d = min(p[0] - x0, x1 - p[0], p[1] - y0, y1 - p[1]) - width / 2 - EDGE + CLEARANCE
                if d < worst[0]:
                    worst = (d, ("edge", None))
        return worst
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
